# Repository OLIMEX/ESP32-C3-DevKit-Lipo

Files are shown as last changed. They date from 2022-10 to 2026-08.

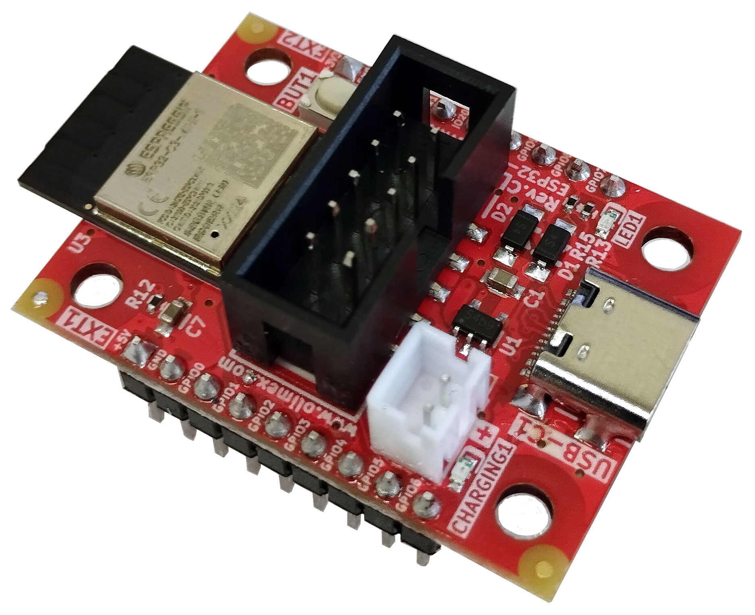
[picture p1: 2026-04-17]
DOCS/Images/ESP32-C3-DevKit-Lipo-1.jpg

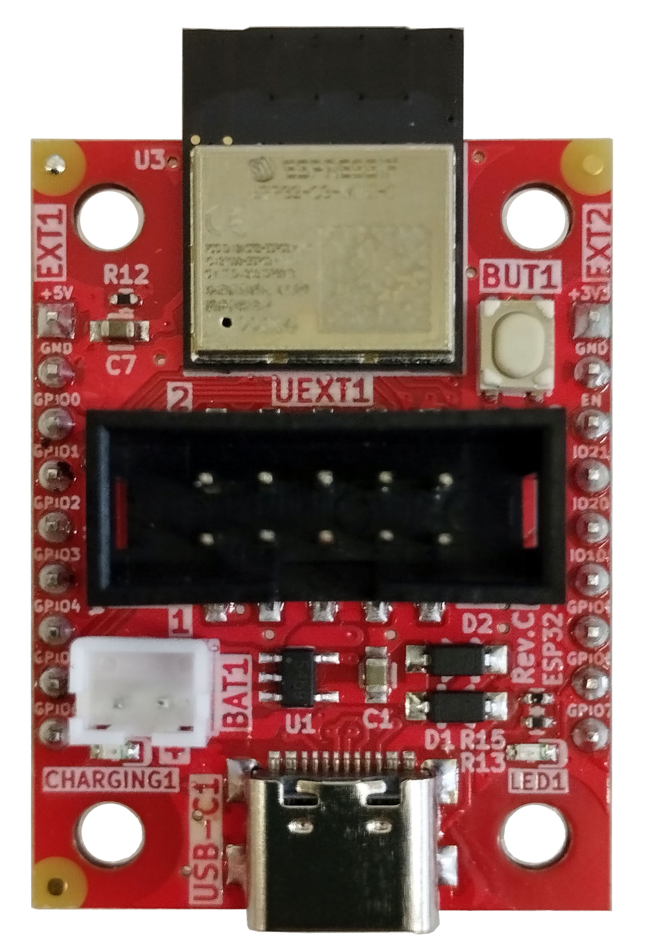
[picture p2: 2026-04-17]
DOCS/Images/ESP32-C3-DevKit-Lipo-2.jpg

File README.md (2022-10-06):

# ESP32-C3-DevKit-Lipo
ESP32-C3-DevKit-Lipo RISC-V development board with USB, JTAG, WIFI, BT5, LiPo battery charger

Product page: https://www.olimex.com/Products/IoT/ESP32-C3/ESP32-C3-DevKit-Lipo/open-source-hardware

## License
* Hardware is released under CERN Open Hardware Licence Version 2 - Strongly Reciprocal https://spdx.org/licenses/CERN-OHL-S-2.0.html
* Software is released under GPL3 License
* Documentation is released under CC BY-SA 3.0 https://creativecommons.org/licenses/by-sa/3.0/

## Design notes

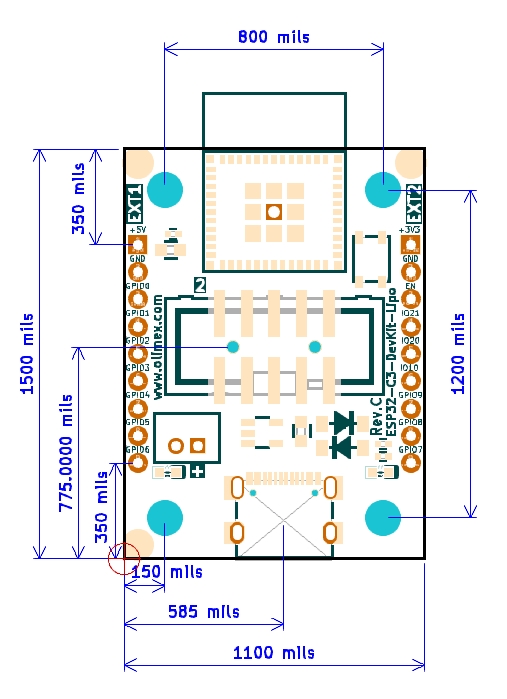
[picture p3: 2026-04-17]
HARDWARE/ESP32-C3-DevKit-Lipo-dimensions.jpg

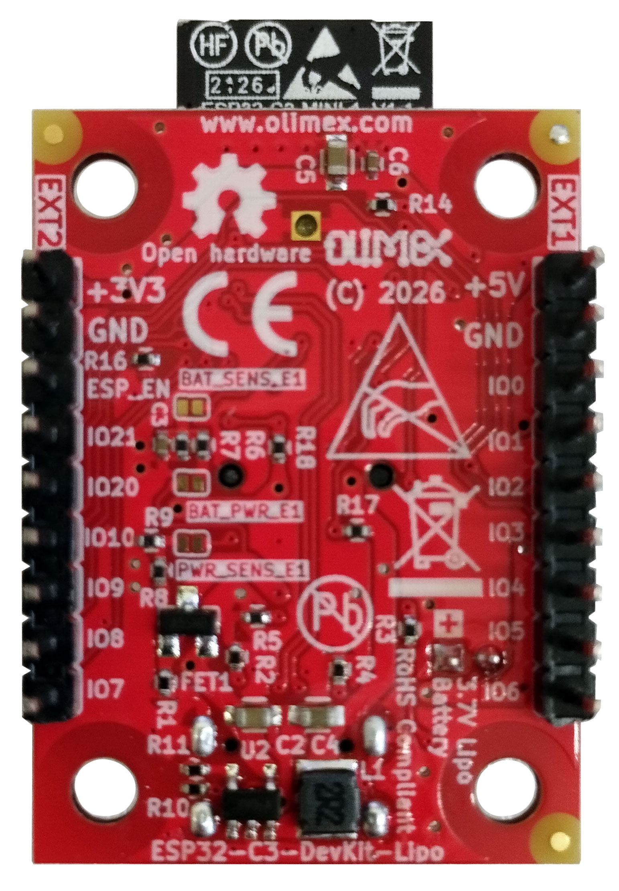
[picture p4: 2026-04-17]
DOCS/Images/ESP32-C3-DevKit-Lipo-3.jpg

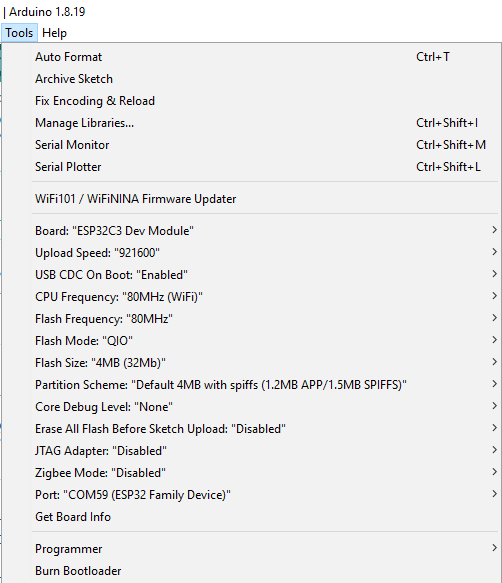
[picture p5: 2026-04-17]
SOFTWARE/Arduino/Arduino-board-settings.jpg

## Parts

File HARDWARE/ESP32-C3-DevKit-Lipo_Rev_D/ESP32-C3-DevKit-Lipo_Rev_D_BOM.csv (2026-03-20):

Id | Designator | Footprint | Quantity | Designation | Supplier and ref
1 | FID1,FID3,FID4,FID6 | Fiducial1x3 | 4 | Fiducial
2 | C1,C2,C5,C4 | C_0603_5MIL_DWS | 4 | 22uF/6.3V/20%/X5R/C0603
3 | R12,R1,R5 | R_0402_5MIL_DWS | 3 | 10k/R0402
4 | R13,R3,R18,R17 | R_0402_5MIL_DWS | 4 | 2.2k/R0402
5 | D2,D1 | SOD-123_1C-2A_KA | 2 | 1N5819S4/SOD123
6 | BAT1 | LIPO_BAT_VERTICAL_DW02S | 1 | DW02S
7 | R15,R14 | R_0402_5MIL_DWS | 2 | 33k/R0402
8 | FID2,FID5 | Fiducial1x3_Paste | 2 | Fiducial
9 | LED1 | LED_0603_KA | 1 | LED/Green/0603
10 | MH1,MH2,MH3,MH4 | Mounting_Hole_Drill-3.3mm_Clerance-7mm | 4 | Mounting_Hole_NPTH
11 | U3 | ESP32--C3--MINI--1 | 1 | ESP32-C3-MINI-1-N4
12 | CHARGING1 | LED_0603_KA | 1 | LED/YELLOW/0603
13 | BUT1 | YTS-A016-X | 1 | YTS-A016-X
14 | U1 | SOT-23-5 | 1 | TP4054-42-SOT25-R
15 | C7 | C_0603_5MIL_DWS | 1 | 1uF/10V/10%/X5R/C0603
16 | USB-C1 | USB2.0_TYPE-C(A40-00119-A52-12) | 1 | USB-C-16P-F(A40-00119-A52-12)
17 | UEXT1 | GBH-254-SMT-10 | 1 | P-B-V-10-LF
18 | BAT_PWR_E1,BAT_SENS_E1,PWR_SENS_E1 | SJ_1_SMALLER | 3 | Opened
19 | R6,R7,R9 | R_0402_5MIL_DWS | 3 | 470k/R0402
20 | R8,R10 | R_0402_5MIL_DWS | 2 | 220k/R0402
21 | L1 | CD32 | 1 | 2.2uH/NRS3015T2R2MNGH/1.5A/3.00x3.00x1.50mm
22 | R11 | R_0402_5MIL_DWS | 1 | 49.9k/1%/R0402
23 | C3,C6 | C_0402_5MIL_DWS | 2 | 100nF/10V/10%/X7R/C0402
24 | FET1 | SOT23 | 1 | IRLML6402TRPbF
25 | EXT1,EXT2 | HN1x9 | 2 | HN1x9
26 | R2,R4 | R_0402_5MIL_DWS | 2 | 5.1k/R0402
27 | U2 | SOT-23-5 | 1 | SY8089AAAC(SOT23-5)
28 | Logo_OLIMEX_2 | Logo_OLIMEX_80 | 1 | Logo_OLIMEX_2
29 | Sign_CE | CE_Sign | 1 | CE_Sign
30 | Sign_Antistatic | Sign_Antistatic | 1 | Sign_Antistatic
31 | Sign_PB-Free | Sign_PB-Free | 1 | Sign_PB-Free
32 | Sign_RecycleBin_1 | Sign_RecycleBin_1 | 1 | Sign_RecycleBin_1
33 | R16 | R_0402_5MIL_DWS | 1 | 100R/R0402

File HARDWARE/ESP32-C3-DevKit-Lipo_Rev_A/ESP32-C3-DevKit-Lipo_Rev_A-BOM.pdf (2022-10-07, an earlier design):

## ESP32-C3-DevKit-Lipo_Rev_A-BOM 09/28/2022

Quantity | Designation | Package | Designator
2 | 2.2k/R0402 | R0402 | R3,R13
2 | 5.1k/R0603 | R0603 | R2,R4
3 | 10k/R0402 | R0402 | R1,R5,R12
2 | 33k/R0402 | R0402 | R14,R15
1 | 49.9k/1%/R0402 | R0402 | R11
2 | 220k/R0402 | R0402 | R8,R10
3 | 470k/R0402 | R0402 | R6,R7,R9
1 | 2.2uH/1.5A/DCR=72mR/ 20%/3.00x3.00x1.50mm/ CD32(NR3015T2R2M) | CD32 | L1
2 | 100nF/10V/10%/X7R/C0402 | C0402 | C3,C6
1 | 1uF/10V/10%/X5R/C0603 | C0603 | C7
4 | 22uF/6.3V/20%/X5R/C0603 | C0603 | C1,C2,C4,C5
2 | 1N5819S4/SOD123 | SOD-123 | D1,D2
1 | LED/YELLOW/0603 | LED_0603 | CHARGING1
1 | LED/Green/0603 | LED_0603 | LED1
1 | WPM2015-3/TR | SOT23 | FET1
1 | BL4054B-42TPRN(SOT23-5) | SOT-23-5 | U1
1 | ESP32-C3-MINI-1-N4 | ESP32- C3- MINI -1 | U3
1 | SY8089AAAC(SOT23-5) | SOT-23-5 | U2
1 | DW02S | DW02S | BAT1
2 | HN1x9 | HN1x9 | EXT1,EXT2
1 | USB-C-16P-F(A40-00119-A52-12) | USB2.0_TYPE-C | USB-C1
1 | WU06S | WU06S | ESP-PROG1
1 | YTS-A016-X | YTS-A016-X | RST1
4 | Opened | SJ_1_SMALLER

BAT_PWR_E1,
BAT_SENS_E1,
PWR_SENS_E1,
3.3V_E1

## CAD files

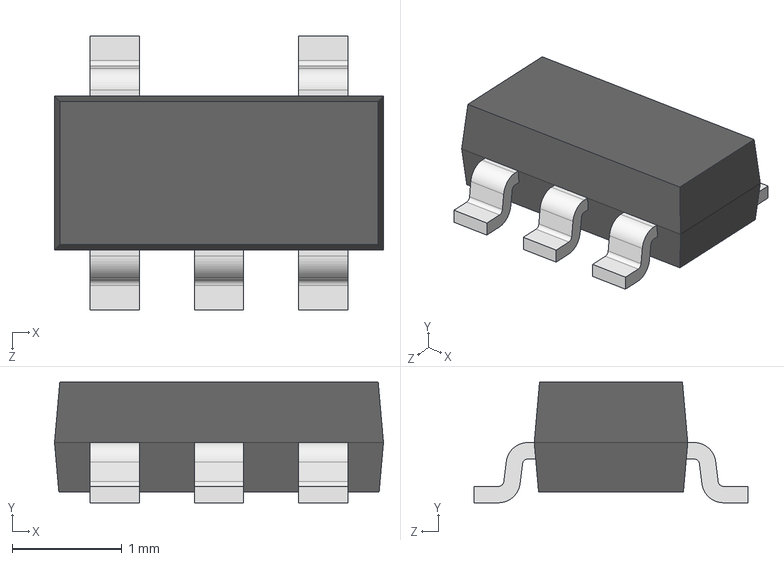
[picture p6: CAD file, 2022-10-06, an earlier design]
HARDWARE/ESP32-C3-DevKit-Lipo_Rev_A/3d/SOT-23-5.step
3.00 x 1.10 x 2.50 mm

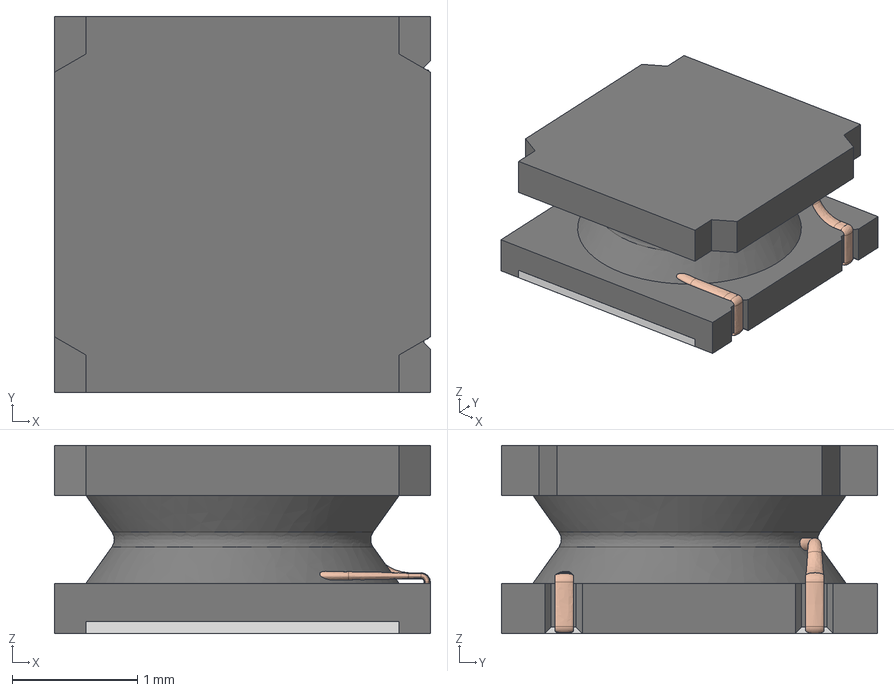
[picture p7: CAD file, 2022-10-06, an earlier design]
HARDWARE/ESP32-C3-DevKit-Lipo_Rev_A/3d/L-CD32_shielded.step
3.00 x 3.00 x 1.50 mm

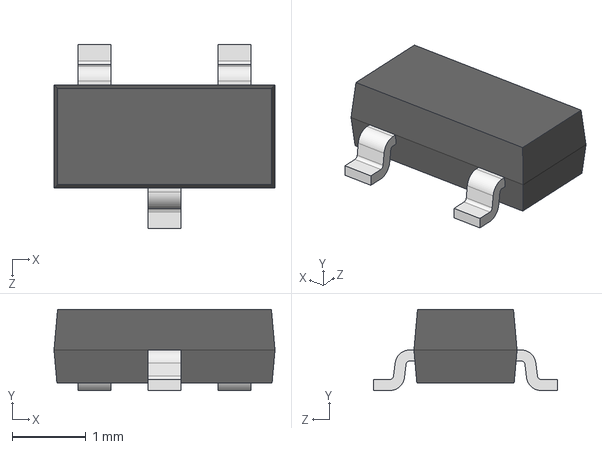
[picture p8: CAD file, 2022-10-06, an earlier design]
HARDWARE/ESP32-C3-DevKit-Lipo_Rev_A/3d/SOT-23.step
3.00 x 1.10 x 2.50 mm

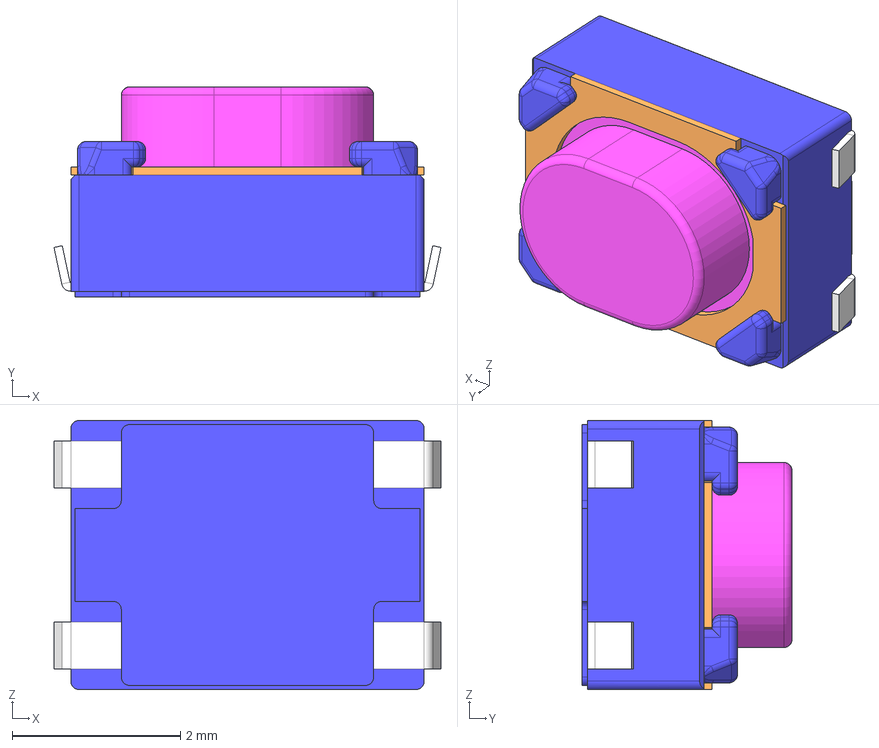
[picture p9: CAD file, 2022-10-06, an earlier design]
HARDWARE/ESP32-C3-DevKit-Lipo_Rev_A/3d/YTS-A016-X(SKRPABE010).stp
4.60 x 2.50 x 3.20 mm

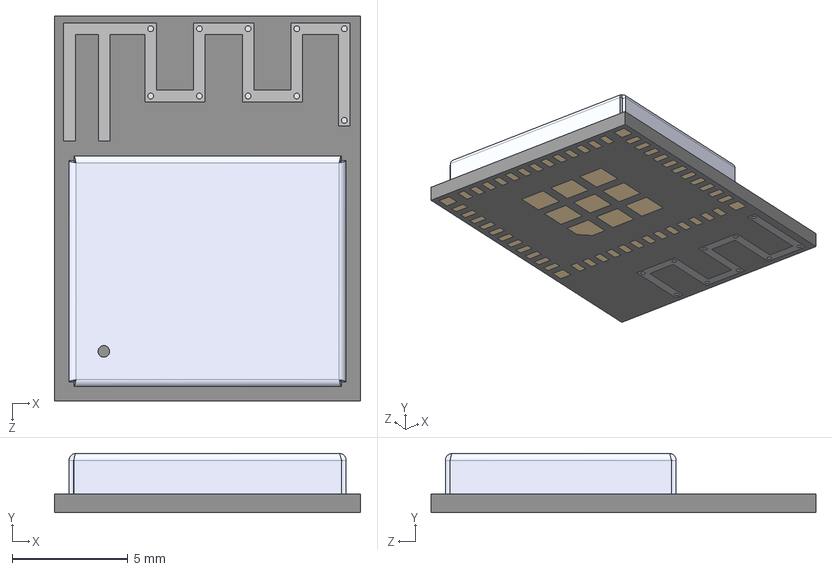
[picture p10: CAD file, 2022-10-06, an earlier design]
HARDWARE/ESP32-C3-DevKit-Lipo_Rev_A/3d/ESP32-C3-MINI-1-N4.STEP
13.2 x 2.55 x 16.6 mm

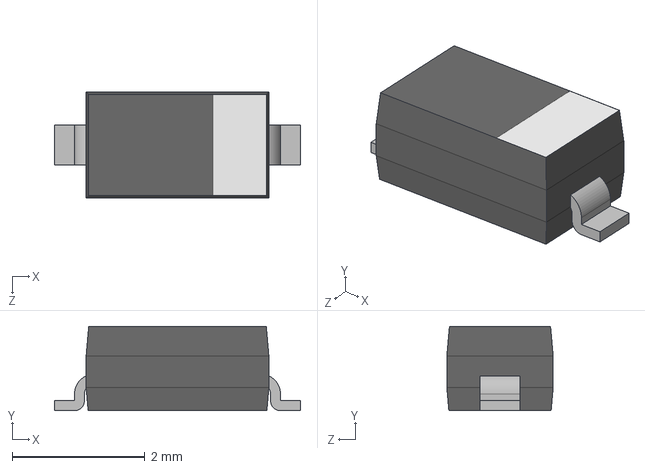
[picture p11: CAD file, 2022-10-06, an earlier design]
HARDWARE/ESP32-C3-DevKit-Lipo_Rev_A/3d/SOD123.step
3.70 x 1.27 x 1.60 mm

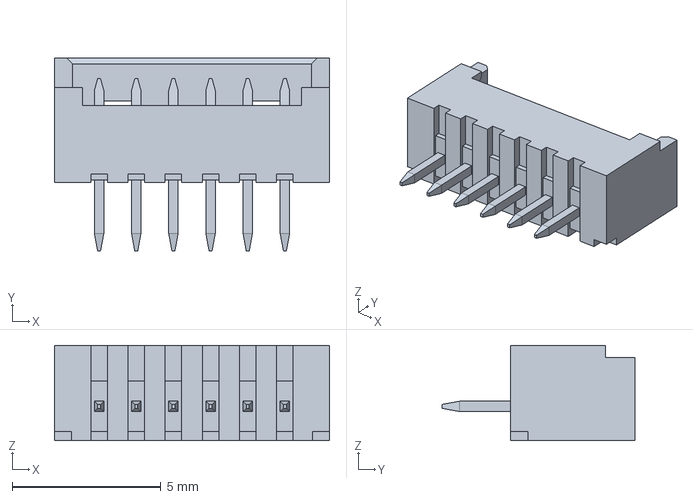
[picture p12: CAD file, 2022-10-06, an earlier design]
HARDWARE/ESP32-C3-DevKit-Lipo_Rev_A/3d/WU06S-Molex_PicoBlade_530470610_1x06_P1.25mm_Vertical.step
9.25 x 6.50 x 3.20 mm

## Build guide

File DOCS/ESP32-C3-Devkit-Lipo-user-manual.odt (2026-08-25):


ESP32-C3-DevKit-Lipo

User Manual

Document version 2.1 August 2026

olimex.com

# What is ESP32-C3-DevKit-Lipo

ESP32-C3-DevKit-Lipo is an Open Source Hardware industrial grade (-25+85ºC) development board with Espressif ESP32-C3-MINI module and WIFI and BLE5 capabilities. It has the following features:

- ESP32-C3-MINI-1N4 module with the following features:
  - RISC-V single core processor running on 160 Mhz
  - 384 KB ROM, 400 KB SRAM (16 KB for cache), 8 KB SRAM in RTC
  - 4 MB embedded flash
  - 2.4 GHz WiFi (802.11 b/g/n) 1T1R mode with data rate up to 150 Mbps
  - Bluetooth® 5 module
- 15 GPIOs
- On-board antenna
- Built-in Li-Po battery charger with STATUS LED, for handheld operations
- Li-Po battery connector for Olimex Li-Po batteries
- User button
- STATUS LED
- UEXT 0.1" step connector
- 4 mount holes
- USB-C connector for powering, debugging, and programming
- EXT1, EXT2 headers with all signals and power supply
- Tiny size: (1.1 x 1.5)" ~ (28 x 38)mm

# Board layout

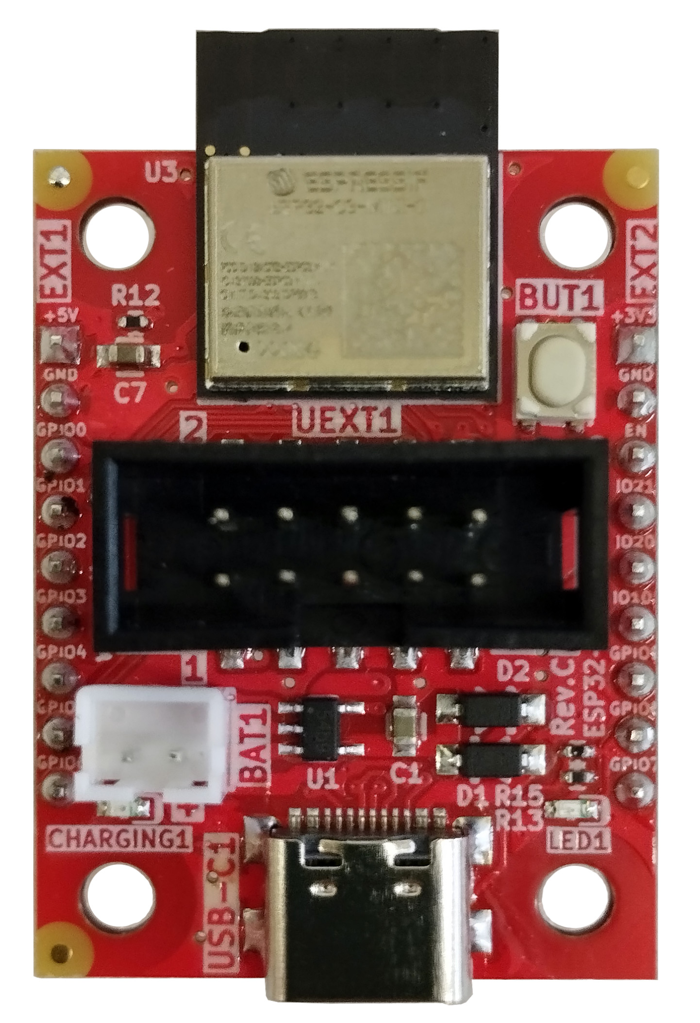
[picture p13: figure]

ESP32-C3-MINI-1

User LED1 - GPIO8

Li-Po battery connector

Battery charger LED indicator

USB C connector

User button BUT1 - GPIO9

UEXT

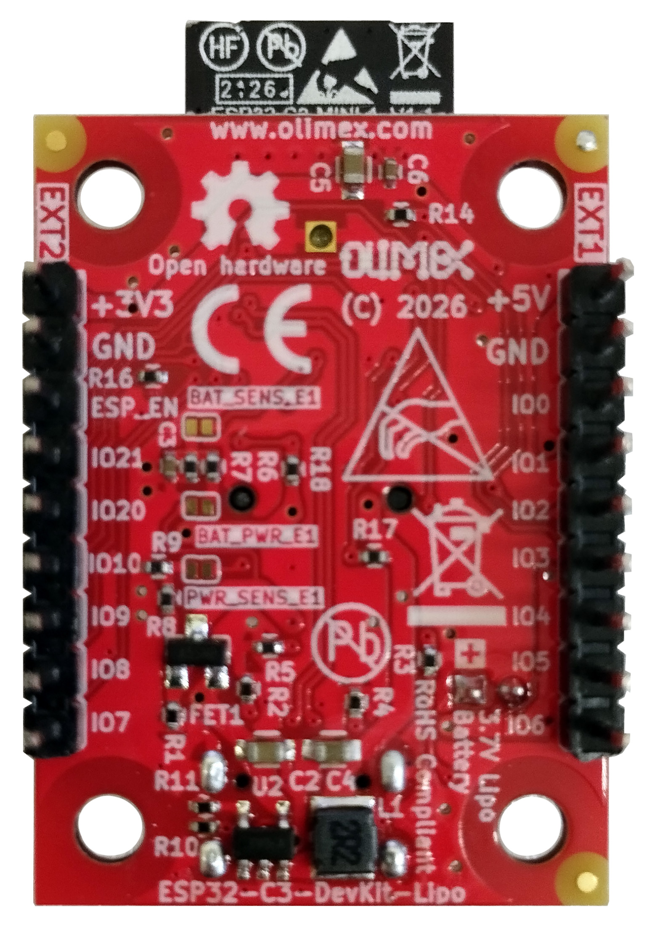
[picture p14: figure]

# ESP32-C3-DevKit-Lipo ordering options

ESP32-C3-DevKit-Lipo can be ordered as:

- ESP32-C3-DevKit-Lipo (https://www.olimex.com/Products/IoT/ESP32-C3/ESP32-C3-DevKit-Lipo/open-source-hardware)

Additional accessories:

- USB-C cable: CABLE-USB-A-C-1M (https://www.olimex.com/Products/Components/Cables/CABLE-USB-A-C-1M/)
- LiPo batteries: Olimex LiPo batteries (https://www.olimex.com/Products/Power/Lipo-battery/)
- Breadboard: BREADBOARD1 (https://www.olimex.com/Products/Breadboarding/BREADBOARD-1/)
- Jumper wires: JW-200x10 (https://www.olimex.com/Products/Breadboarding/JUMPER-WIRES/JW-200x10/), JW-200x10-FM (https://www.olimex.com/Products/Breadboarding/JUMPER-WIRES/JW-200x10-FM/)

# ESP32-C3-DevKit-Lipo Open Source Licensee

ESP32-C3-DevKit-Lipo is Open Source Hardware, ESP32-C3-DevKit-Lipo is certified Open Source Hardware with UID BG000083: https://certification.oshwa.org/bg000083.html

The Hardware files are released under CERN OSHW licensee (https://github.com/OLIMEX/USB-gLINK/blob/master/cern_ohl_s_v2.pdf).

The software is released under GPL 3 licensee (https://github.com/OLIMEX/USB-gLINK/blob/master/LICENSE).

The documentation is released under CC BY-SA 3.0 (https://creativecommons.org/licenses/by-sa/3.0/) licensee.

# ESP32-C3-DevKit-Lipo software installation

How to program the board? Usually you use software that has support for ESP32-C3 chip and then plug the board to the USB. No extra steps with the hardware are needed but if you have trouble you can force the board into bootloader mode – disconnect the USB cable, press and hold button BUT1, connect the USB cable, release button BUT1.

Esspresif guide for Arduino IDE installation (https://docs.espressif.com/projects/arduino-esp32/en/latest/installing.html)

You can find simple Arduino demo here: Button, LED, serial demo (https://github.com/OLIMEX/ESP32-C3-DevKit-Lipo/tree/main/SOFTWARE/Arduino)

Esspressif guide for PlatformIO installation (https://docs.espressif.com/projects/arduino-esp32/en/latest/installing.html)

Espressif ESP-IDF installation (https://github.com/espressif/esp-idf)

JTAG debugging installation (https://docs.espressif.com/projects/esp-idf/en/latest/esp32c3/api-guides/jtag-debugging/index.html)

# ESP32-C3-DevKit-Lipo pinout description

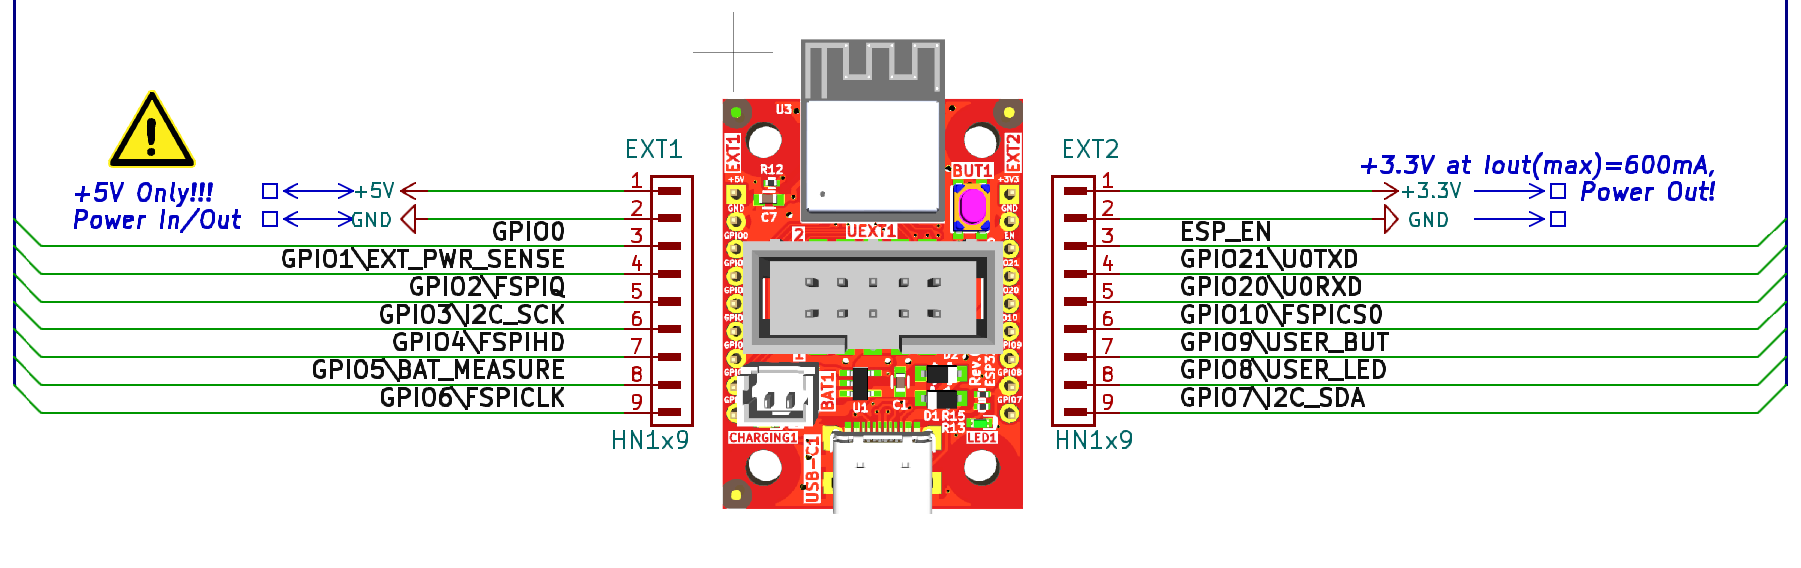
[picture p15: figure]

# UEXT pinout

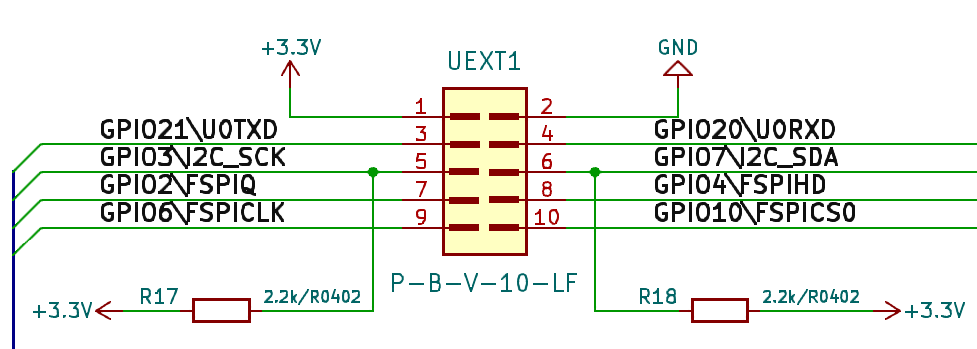
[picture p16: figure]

# External power sense and battery measurement

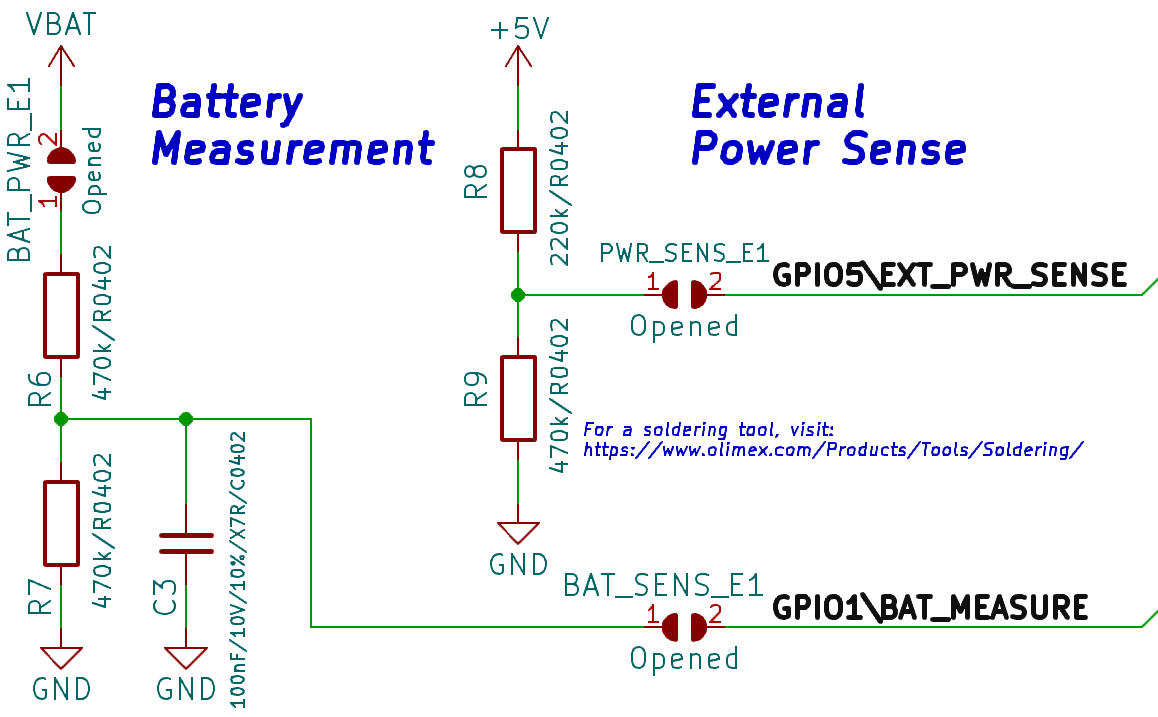
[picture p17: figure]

There are external power sense and battery measurement circuits. By default these are disconnected and can be enabled if you solder together a couple of PTH jumpers.

If you wish to enable the external power sense function, close PWR_SENSE_E1 – this function allows you to detect whether the board is powered from the battery or externally – very helpful if you want to conserve battery when main power supply is missing. Notice the voltage divider R8 and R9 (220K and 470K) and consider the resistor values in your calculations about the threshold. The pin that handles the external power sense function is GPIO5.

If you wish to enable the battery measurement function – you need to close two jumpers (solder pads of each jumper together) – BAT_PWR_E1 and BAT_SENS_E1. This function helps keeping track of the voltage of the battery connected so you can take certain precautions when the voltage of battery goes dangerously low. Notice the voltage divider R6 and R7 (470k and 470k) and consider the resistor values in your calculations. The pin that handles the external power sense function is GPIO1.

Note! The power sense and battery measurement pins were swapped in hardware revision D. Refer to the hardware revision changes document and the schematics for further info.

# ESP32-C3-DevKit-Lipo power supply and consumption

- 0.2A @ Active operation
- 22mA @ Idle
- 3mA @ Sleep
- 20uA @ Power off

# ESP32-C3-DevKit-Lipo dimensions

The dimensions apply to hardware revisions C and newer. Dimensions for revision B boards are available at our GitHub.

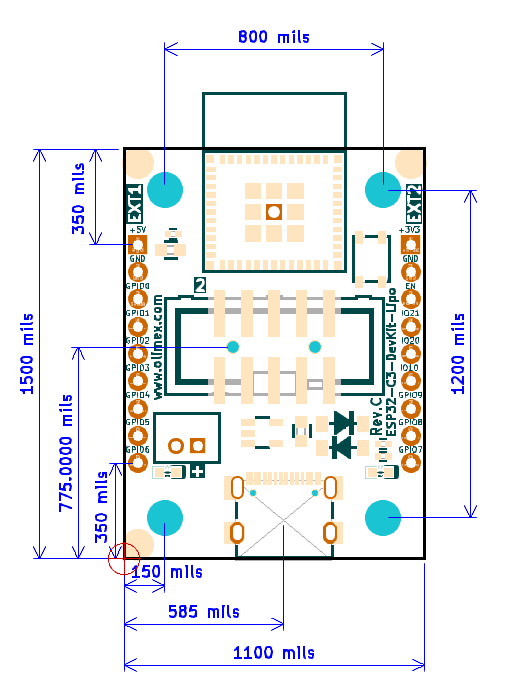
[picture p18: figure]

# ESP32-C3-DevKit-Lipo schematic

ESP32-C3-DevKit-Lipo schematics (including for older revisons) are available at GitHub hardware (https://github.com/OLIMEX/ESP32-C3-DevKit-Lipo/tree/main/HARDWARE)

Hardware revision changes can be found in this text document: Hardware revision changes text at GitHub (https://github.com/OLIMEX/ESP32-C3-DevKit-Lipo/blob/main/HARDWARE/Hardware-revision-changes.txt)

Notice that there were major changes in the hardware design in hardware revision C (added UEXT connector; removed PROG connector; removed reset button but added user button; rotated BAT1 connector; and more).

# Document version history

Revision 1.0 September 2022

- Initial release

Revision 2.0 April 2026

- Edited the document to fit hardware revision C of the board

- Documents for hardware revision B boards available at GitHub for reference

Revision 2.1 August 2026

- Edited the document to fit hardware revision D of the board (the only change is the swap of battery measurement and external power pins)

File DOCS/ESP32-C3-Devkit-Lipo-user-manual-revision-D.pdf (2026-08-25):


# ESP32-C3-DevKit-Lipo User Manual

## Document version 2.1 August 2026

# olimex.com

## Table of Contents

## What is ESP32-C3-DevKit-Lipo

ESP32-C3-DevKit-Lipo is an Open Source Hardware industrial grade (-25+85ºC) development board with Espressif ESP32-C3-MINI module and WIFI and BLE5 capabilities. It has the following features:

- ESP32-C3-MINI-1N4 module with the following features:
- RISC-V single core processor running on 160 Mhz
- 384 KB ROM, 400 KB SRAM (16 KB for cache), 8 KB SRAM in RTC
- 4 MB embedded flash
- 2.4 GHz WiFi (802.11 b/g/n) 1T1R mode with data rate up to 150 Mbps
- Bluetooth® 5 module
- 15 GPIOs
- On-board antenna
- Built-in Li-Po battery charger with STATUS LED, for handheld operations
- Li-Po battery connector for Olimex Li-Po batteries
- User button
- STATUS LED
- UEXT 0.1" step connector
- 4 mount holes
- USB-C connector for powering, debugging, and programming
- EXT1, EXT2 headers with all signals and power supply
- Tiny size: (1.1 x 1.5)" ~ (28 x 38)mm

## Board layout

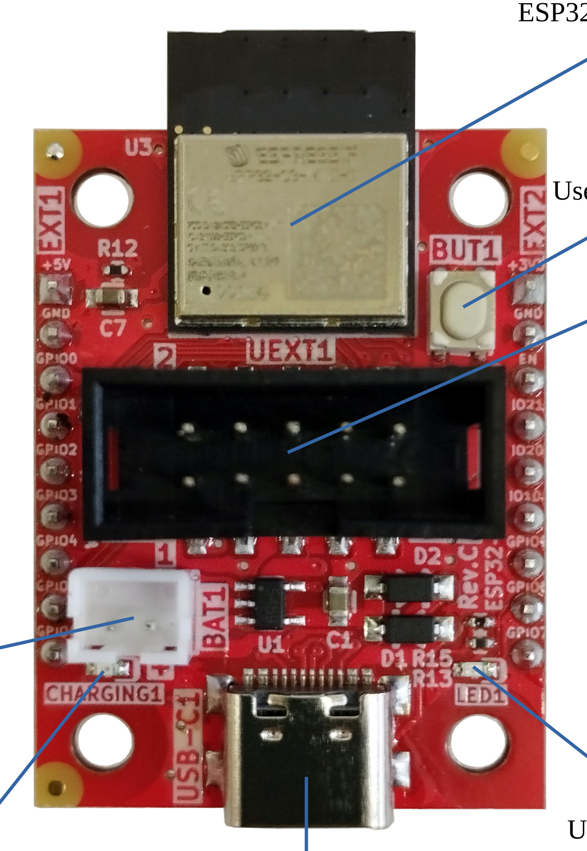
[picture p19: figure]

User LED1 - GPIO8

Li-Po battery
connector

Battery charger LED
indicator
USB C
connector

User button BUT1 - GPIO9

ESP32-C3-MINI-1

UEXT


## ESP32-C3-DevKit-Lipo ordering options

ESP32-C3-DevKit-Lipo can be ordered as:
- ESP32-C3-DevKit-Lipo (https://www.olimex.com/Products/IoT/ESP32-C3/ESP32-C3-DevKit-Lipo/open-source-hardware)
Additional accessories:
- USB-C cable: CABLE-USB-A-C-1M (https://www.olimex.com/Products/Components/Cables/CABLE-USB-A-C-1M/)
- LiPo batteries: Olimex LiPo batteries (https://www.olimex.com/Products/Power/Lipo-battery/)
- Breadboard: BREADBOARD1 (https://www.olimex.com/Products/Breadboarding/BREADBOARD-1/)
- Jumper wires: JW-200x10, (https://www.olimex.com/Products/Breadboarding/JUMPER-WIRES/JW-200x10/) JW-200x10-FM (https://www.olimex.com/Products/Breadboarding/JUMPER-WIRES/JW-200x10-FM/)

## ESP32-C3-DevKit-Lipo Open Source Licensee

ESP32-C3-DevKit-Lipo is Open Source Hardware, ESP32-C3-DevKit-Lipo is certified Open Source Hardware with UID BG000083: https://certification.oshwa.org/bg000083.html

The Hardware files are released under CERN OSHW licensee. (https://github.com/OLIMEX/USB-gLINK/blob/master/cern_ohl_s_v2.pdf)
The software is released under GPL 3 licensee. (https://github.com/OLIMEX/USB-gLINK/blob/master/LICENSE)
The documentation is released under CC BY-SA 3.0 (https://creativecommons.org/licenses/by-sa/3.0/) licensee.

## ESP32-C3-DevKit-Lipo software installation

How to program the board? Usually you use software that has support for ESP32-C3 chip and then plug the board to the USB. No extra steps with the hardware are needed but if you have trouble you can force the board into bootloader mode – disconnect the USB cable, press and hold button BUT1, connect the USB cable, release button BUT1.

Esspresif guide for Arduino IDE installation (https://docs.espressif.com/projects/arduino-esp32/en/latest/installing.html)
You can find simple Arduino demo here: Button, LED, serial demo (https://github.com/OLIMEX/ESP32-C3-DevKit-Lipo/tree/main/SOFTWARE/Arduino)

Esspressif guide for PlatformIO installation (https://docs.espressif.com/projects/arduino-esp32/en/latest/installing.html)
Espressif ESP-IDF installation (https://github.com/espressif/esp-idf)
JTAG debugging installation (https://docs.espressif.com/projects/esp-idf/en/latest/esp32c3/api-guides/jtag-debugging/index.html)

## ESP32-C3-DevKit-Lipo pinout description

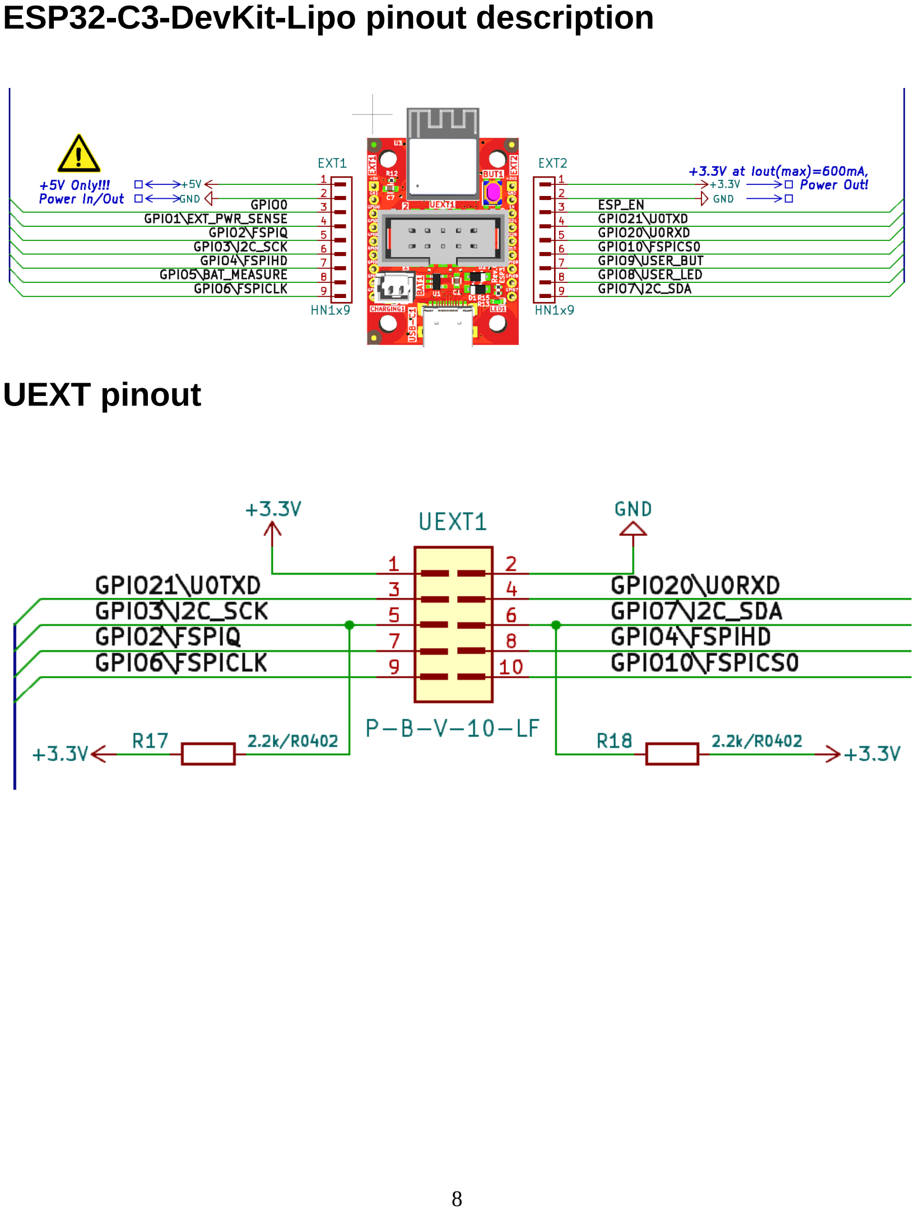
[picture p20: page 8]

## UEXT pinout

## External power sense and battery measurement


There are external power sense and battery measurement circuits. By default these are disconnected and can be enabled if you solder together a couple of PTH jumpers.
If you wish to enable the external power sense function, close PWR_SENSE_E1 – this function allows you to detect whether the board is powered from the battery or externally – very helpful if you want to conserve battery when main power supply is missing. Notice the voltage divider R8 and R9 (220K and 470K) and consider the resistor values in your calculations about the threshold. The pin that handles the external power sense function is GPIO5.
If you wish to enable the battery measurement function – you need to close two jumpers (solder pads of each jumper together) – BAT_PWR_E1 and BAT_SENS_E1. This function helps keeping track of the voltage of the battery connected so you can take certain precautions when the voltage of battery goes dangerously low. Notice the voltage divider R6 and R7 (470k and 470k) and consider the resistor values in your calculations. The pin that handles the external power sense function is GPIO1.
Note! The power sense and battery measurement pins were swapped in hardware revision D. Refer to the hardware revision changes document and the schematics for further info.

## ESP32-C3-DevKit-Lipo power supply and consumption

- 0.2A @ Active operation
- 22mA @ Idle
- 3mA @ Sleep
- 20uA @ Power off

## ESP32-C3-DevKit-Lipo dimensions

The dimensions apply to hardware revisions C and newer. Dimensions for revision B boards are available at our GitHub.

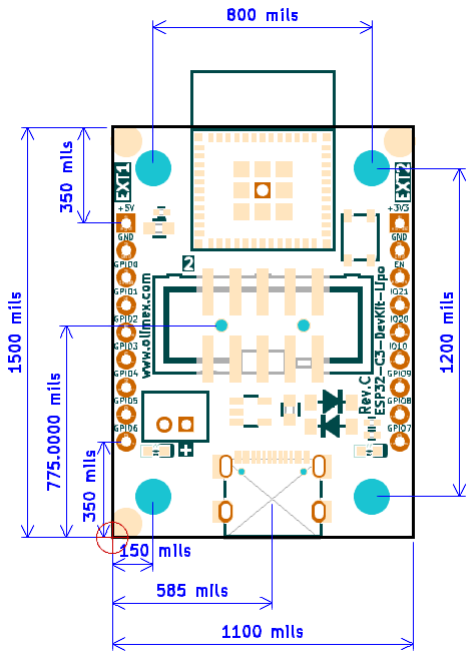
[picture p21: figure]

## ESP32-C3-DevKit-Lipo schematic

ESP32-C3-DevKit-Lipo schematics (including for older revisons) are available at GitHub hardware (https://github.com/OLIMEX/ESP32-C3-DevKit-Lipo/tree/main/HARDWARE) Hardware revision changes can be found in this text document: Hardware revision changes text at GitHub (https://github.com/OLIMEX/ESP32-C3-DevKit-Lipo/blob/main/HARDWARE/Hardware-revision-changes.txt)
Notice that there were major changes in the hardware design in hardware revision C (added UEXT connector; removed PROG connector; removed reset button but added user button; rotated BAT1 connector; and more).

## Document version history

Revision 1.0 September 2022
- Initial release
Revision 2.0 April 2026
- Edited the document to fit hardware revision C of the board
- Documents for hardware revision B boards available at GitHub for reference
Revision 2.1 August 2026
- Edited the document to fit hardware revision D of the board (the only change is the swap of battery measurement and external power pins)

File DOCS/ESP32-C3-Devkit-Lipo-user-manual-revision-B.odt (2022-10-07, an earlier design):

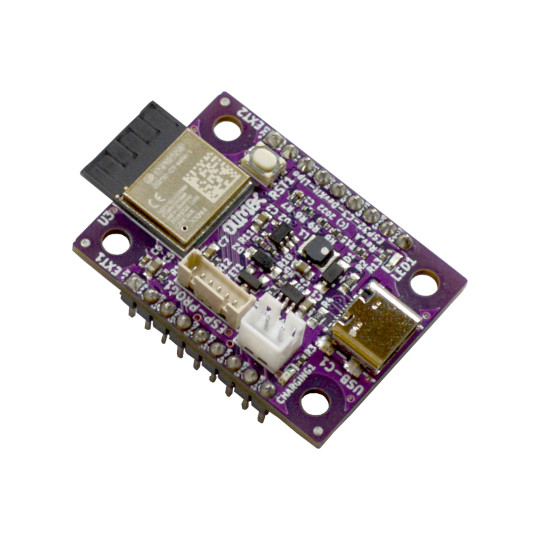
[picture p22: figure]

ESP32-C3-DevKit-Lipo

User Manual

Rev.1.0 September 2022

olimex.com

# What is ESP32-C3-DevKit-Lipo

ESP32-C3-DevKit-Lipo is Open Source Hardware Industrial grade -25+85ºC development board with:

- ESP32-C3 RISC-V single core processor runninig on 160 Mhz
- 384 KB ROM, 400 KB SRAM (16 KB for cache), 8 KB SRAM in RTC
- 4 MB embedded flash
- 2.4 GHz WiFi (802.11 b/g/n) 1T1R mode with data rate up to 150 Mbps
- Bluetooth® 5 module
- 15 GPIOs
- Onboard antenna
- Build in LiPo battery charger with STATUS LED, for handheld operations
- Lipo battery connector for Olimex LiPo batteries
- RESET button
- STATUS LED
- ICSP programming connector for rescue with ESP-PROG-C
- 4 mount holes
- USB-C connector for Debugging and Programming
- two soldered EXT headers with all signals and power supply

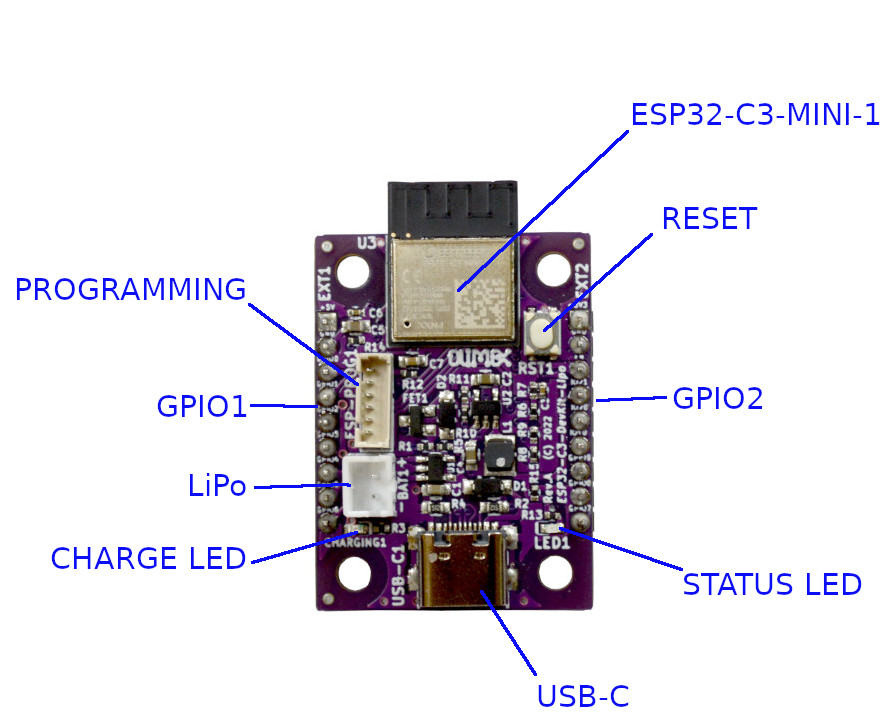
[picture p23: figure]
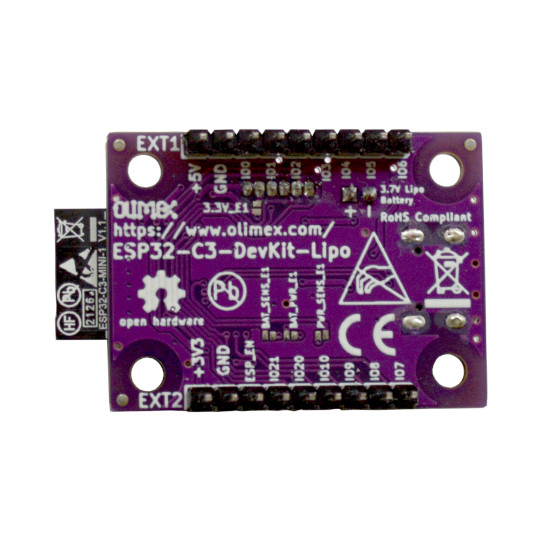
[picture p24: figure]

# ESP32-C3-DevKit-Lipo ordering options

ESP32-C3-DevKit-Lipo can be ordered as:

- ESP32-C3-DevKit-Lipo (https://www.olimex.com/Products/IoT/ESP32-C3/ESP32-C3-DevKit-Lipo/open-source-hardware)

Additional accessories:

USB-C cable: CABLE-USB-A-C-1M (https://www.olimex.com/Products/Components/Cables/CABLE-USB-A-C-1M/)

LiPo batteries: Olimex LiPo batteries (https://www.olimex.com/Products/Power/Lipo-battery/)

Breadboard: BREADBOARD1 (https://www.olimex.com/Products/Breadboarding/BREADBOARD-1/)

Jumper wires: JW-200x10 (https://www.olimex.com/Products/Breadboarding/JUMPER-WIRES/JW-200x10/), JW-200x10-FM (https://www.olimex.com/Products/Breadboarding/JUMPER-WIRES/JW-200x10-FM/)

# ESP32-C3-DevKit-Lipo Open Source Licensee

ESP32-C3-DevKit-Lipo is Open Source Hardware.

The Hardware files are released under CERN OSHW licensee (https://github.com/OLIMEX/USB-gLINK/blob/master/cern_ohl_s_v2.pdf).

The software is released under GPL 3 licensee (https://github.com/OLIMEX/USB-gLINK/blob/master/LICENSE).

The documentation is released under CC BY-SA 3.0 (https://creativecommons.org/licenses/by-sa/3.0/) licensee.

# ESP32-C3-DevKit-Lipo software installation

Esspresif guide for Arduino IDE installation (https://docs.espressif.com/projects/arduino-esp32/en/latest/installing.html).

Esspressif guide for PlatformIO installation (https://docs.espressif.com/projects/arduino-esp32/en/latest/installing.html).

Espressif ESP-IDF installation (https://github.com/espressif/esp-idf).

JTAG debugging installation (https://docs.espressif.com/projects/esp-idf/en/latest/esp32c3/api-guides/jtag-debugging/index.html).

# ESP32-C3-DevKit-Lipo pinout description:

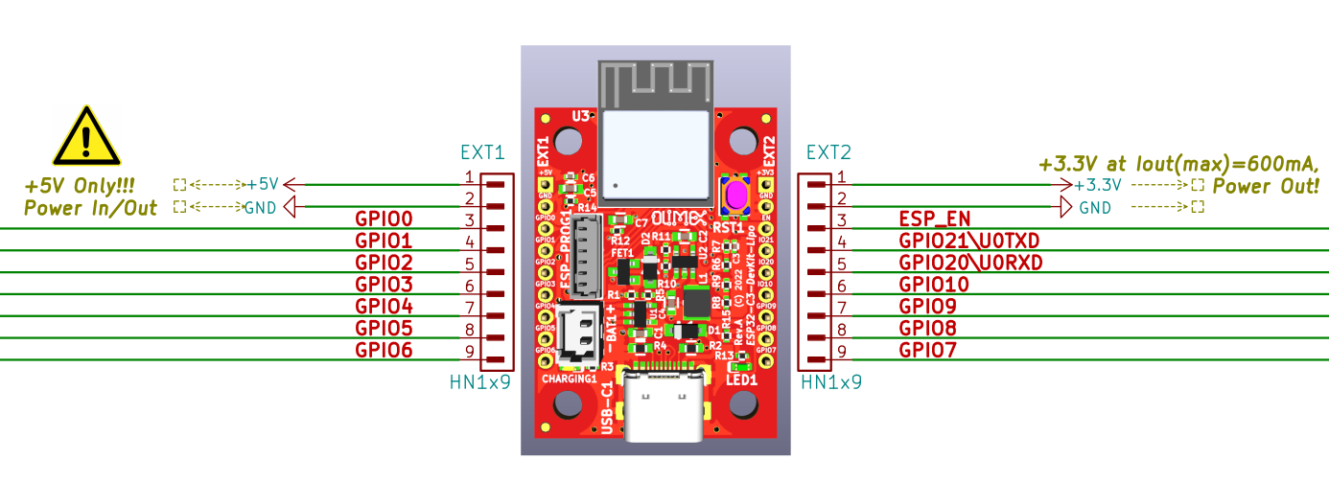
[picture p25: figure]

# ESP32-C3-DevKit-Lipo power supply and consumption

- 0.2A @ Active operation
- 22mA @ Idle
- 3mA @ Sleep
- 20 uA @ Power off

# ESP32-C3-DevKit-Lipo dimensions

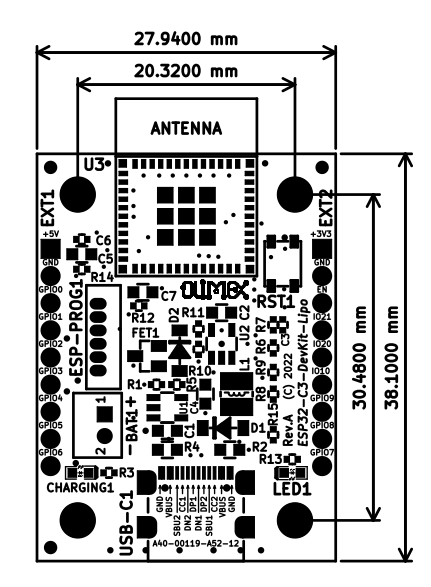
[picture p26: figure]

# ESP32-C3-DevKit-Lipo schematic

# ESP32-C3-DevKit-Lipo schematic on GitHub (https://github.com/OLIMEX/ESP32-C3-DevKit-Lipo/HARDWARE/ESP32-C3-DevKit-Lipo_Rev_A/ESP32-C3-DevKit-Lipo_Rev_A.pdf)

# Revision History

Revision 1.0 September 2022

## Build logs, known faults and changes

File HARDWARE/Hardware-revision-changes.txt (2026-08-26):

========
Hardware revision B
========

Initial release

========
Hardware revision C
========

Major changes compared to revision B:

1. Moved the project to KiCAD 7.
2. Added UEXT connector.
3. Removed ESP-PROG connector.
4. Rotated BAT1 connector.
5. Changed some GPIOs - battery measruement pin is now GPIO5 and external power sense is GPIO1.

========
Hardware revision D
========

Preliminary, unreleased.

1. Reverted the change to the GPIOs responsible for battery sense and battery measurement. This is because ADC2 is used by the WIFI module and there might be confilct.
GPIO5 now used for external power sense and GPIO1 now used for battery measurement.

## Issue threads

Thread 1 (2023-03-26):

GPIO 20 and GPIO 21

elpiel, 2023-03-26:
I see that GPIO 20 has a voltage divider as well as GPIO 21 for power sensing of the 5v.

Could you explain how these pins can be used for reading out the battery measurement and the external power?

Especially what are BAT_PWR_E1, BAT_SENS_E1 and PWR_SENS_E1? And how they can be used.
I tried reading them with ADC but I believe that I'm missing out something because I always get 2000 (with 11db atten. set up).

DanKoloff, 2023-03-28:
By default both external power sense and battery measurement functions are not enabled. To enable external power sense you need to close jumper PWR-SENS_E1 (solder its pads together), then use GPIO4 for monitoring.

Same for battery measurement but you need to close two other SMT jumpers, BAT_PWR_E1 and BAT_SENS_E1. After closing the jumpers use GPIO3 for measurement.

We have code for another board, just put the proper GPIOs:

https://github.com/OLIMEX/ESP32-POE/blob/master/SOFTWARE/ARDUINO/ESP32_PoE_PowerReading/ESP32_PoE_PowerReading.ino

elpiel, 2023-03-28:
#### ADC power sense & battery measurement
Great! I did solder them but now I always get a value of 4095 on the ADC reading with 11db attenuation.

#### 3.3V_E1
There's another enable jumper, would you mind telling me when should I use it? It's connected to the debug

PS: It's good to mention that I have the Rev A.

DanKoloff, 2023-03-28:
Did you try the code I linked with:

#define POWER_SENSE 4
#define BATTERY 3

Usually you would never need to close 3.3V_E1. It is used when you want to power your ESP32-C3-DevKit-Lipo board from the ESP-PROG1 connector, but you usually power the board from the USB. ESP-PROG1 connector fits ESP-PROG tool:

https://www.olimex.com/Products/IoT/Programmer/ESP-PROG/open-source-hardware

elpiel, 2023-03-28:
Yes, I did check it, however, I'm using Rust and I also asked in the esp-rs matrix, it appears that they currently don't do calibration in the HAL (hardware abstraction layer) crate and documentation on this is very scares to implement it.
This is the cause of the issue.

elpiel, 2023-03-28:
Would be nice to mention GPIO3 & GPIO4 in the docs.
It's a very useful feature to have battery measurement and power sense the way you've added it to board.

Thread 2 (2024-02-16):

Serial Monitor not working

dreaquil, 2024-02-16:
I am trying to get a simple sketch running on the ESP32 C3. I am able to upload the sketch successfully but the serial monitor is blank. Any thoughts as to why this might be?

This is the sketch:

```
void setup(){
  Serial.begin(115200);
}

void loop(){
  Serial.println("Hello from ESP32-C3!");
  delay(1000);
}
```

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

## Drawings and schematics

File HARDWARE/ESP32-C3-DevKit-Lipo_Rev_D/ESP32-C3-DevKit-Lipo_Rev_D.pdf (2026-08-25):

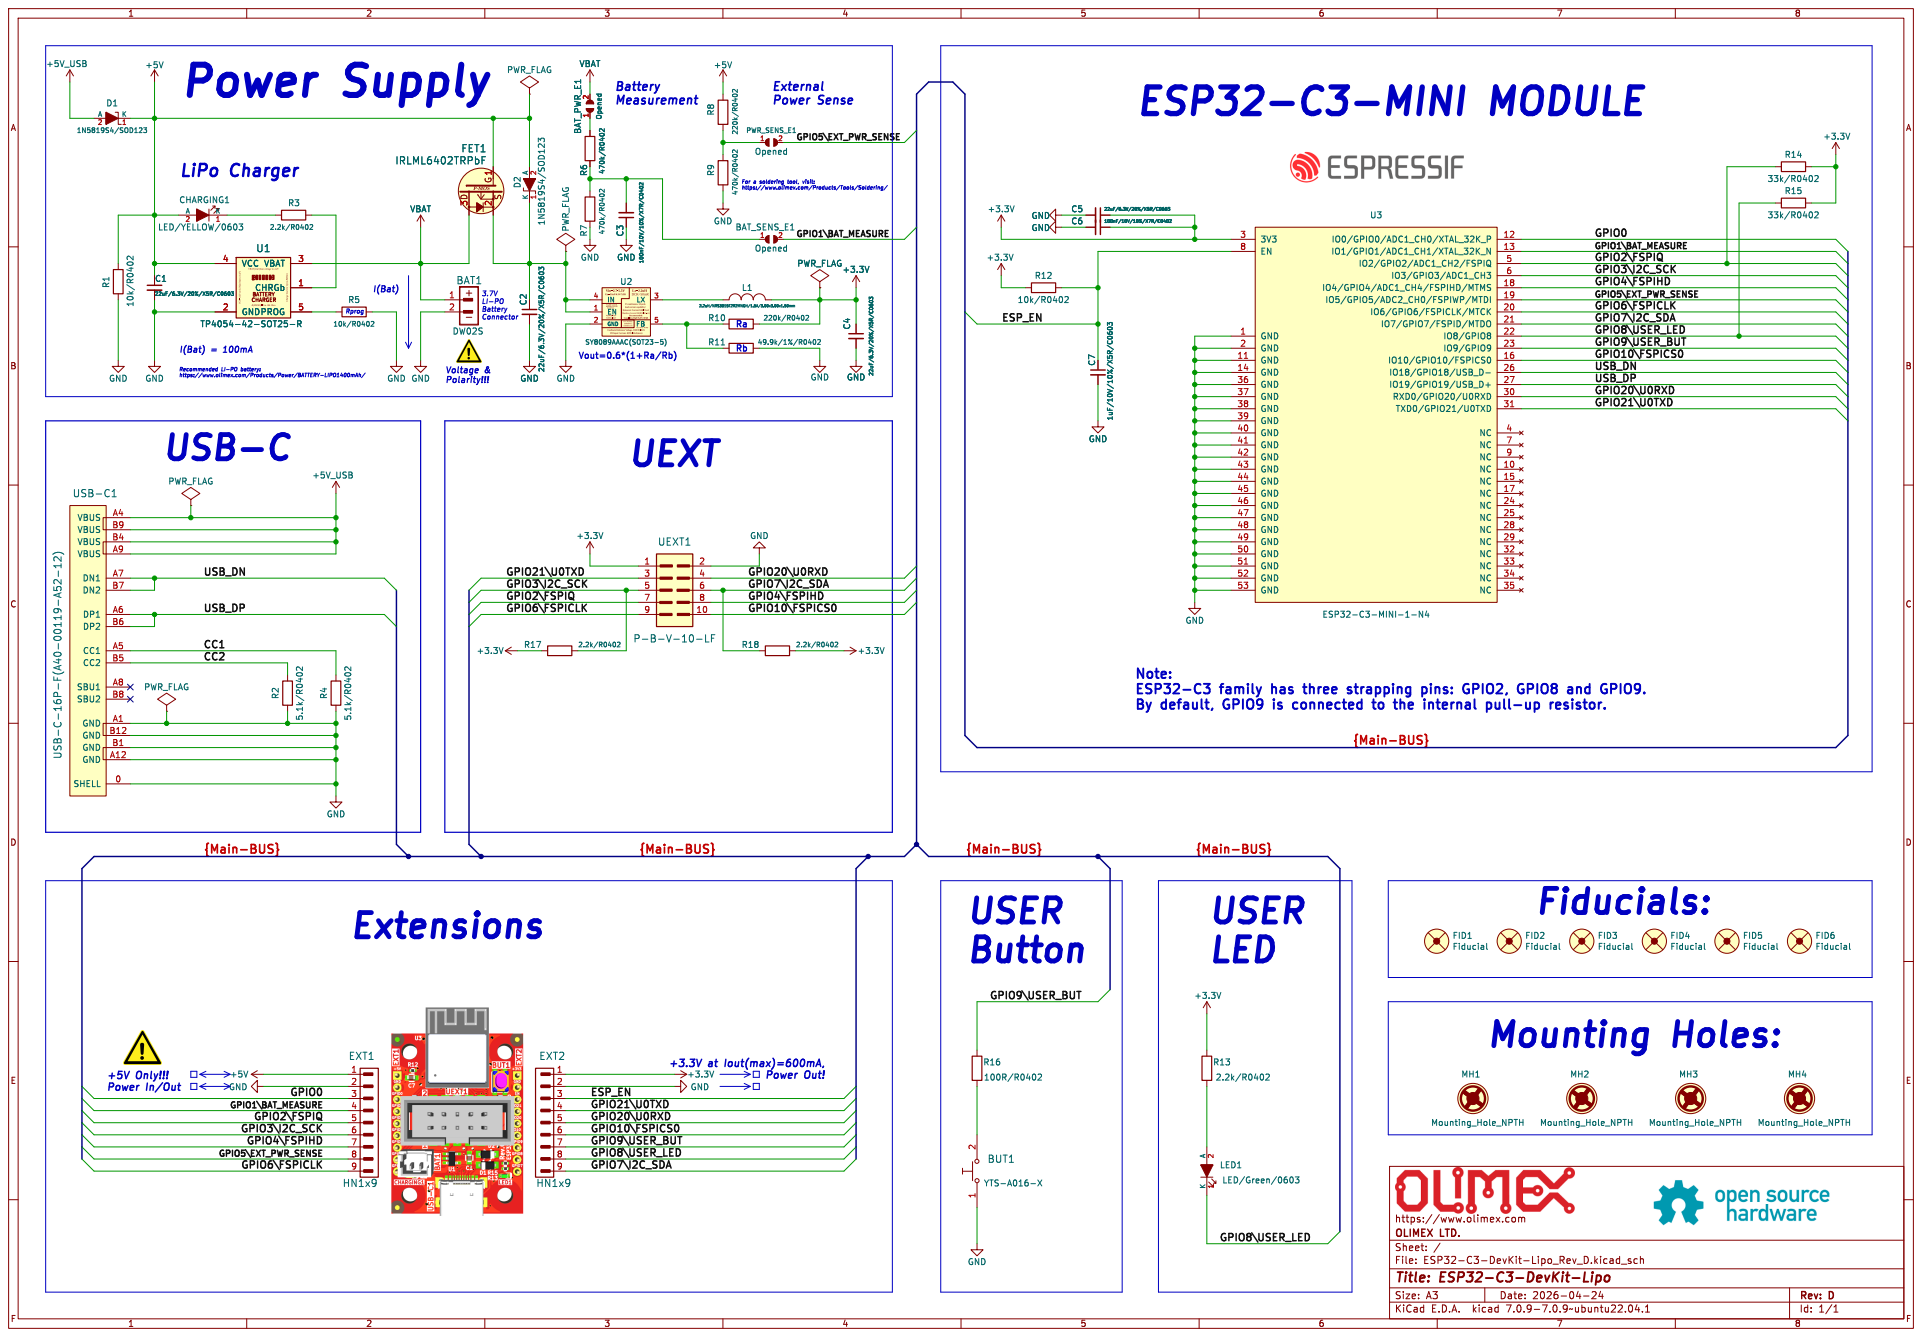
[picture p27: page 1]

Rprog Recommended LI-PO battery: https://www.olimex.com/Products/Power/BATTERY-LIPO1400mAh/ I(Bat) = 100mA
TP4054-42-SOT25-R

Donotfloat. Enablecontrol. FB Input Current,I(FB)=50nA(max) FeedbackReferenceVoltage,V(REF)=0.6V

+5V Only!!! Power In/Out

+3.3V at Iout(max)=600mA, Power Out!

Id: 1/1 Title: ESP32-C3-DevKit-Lipo

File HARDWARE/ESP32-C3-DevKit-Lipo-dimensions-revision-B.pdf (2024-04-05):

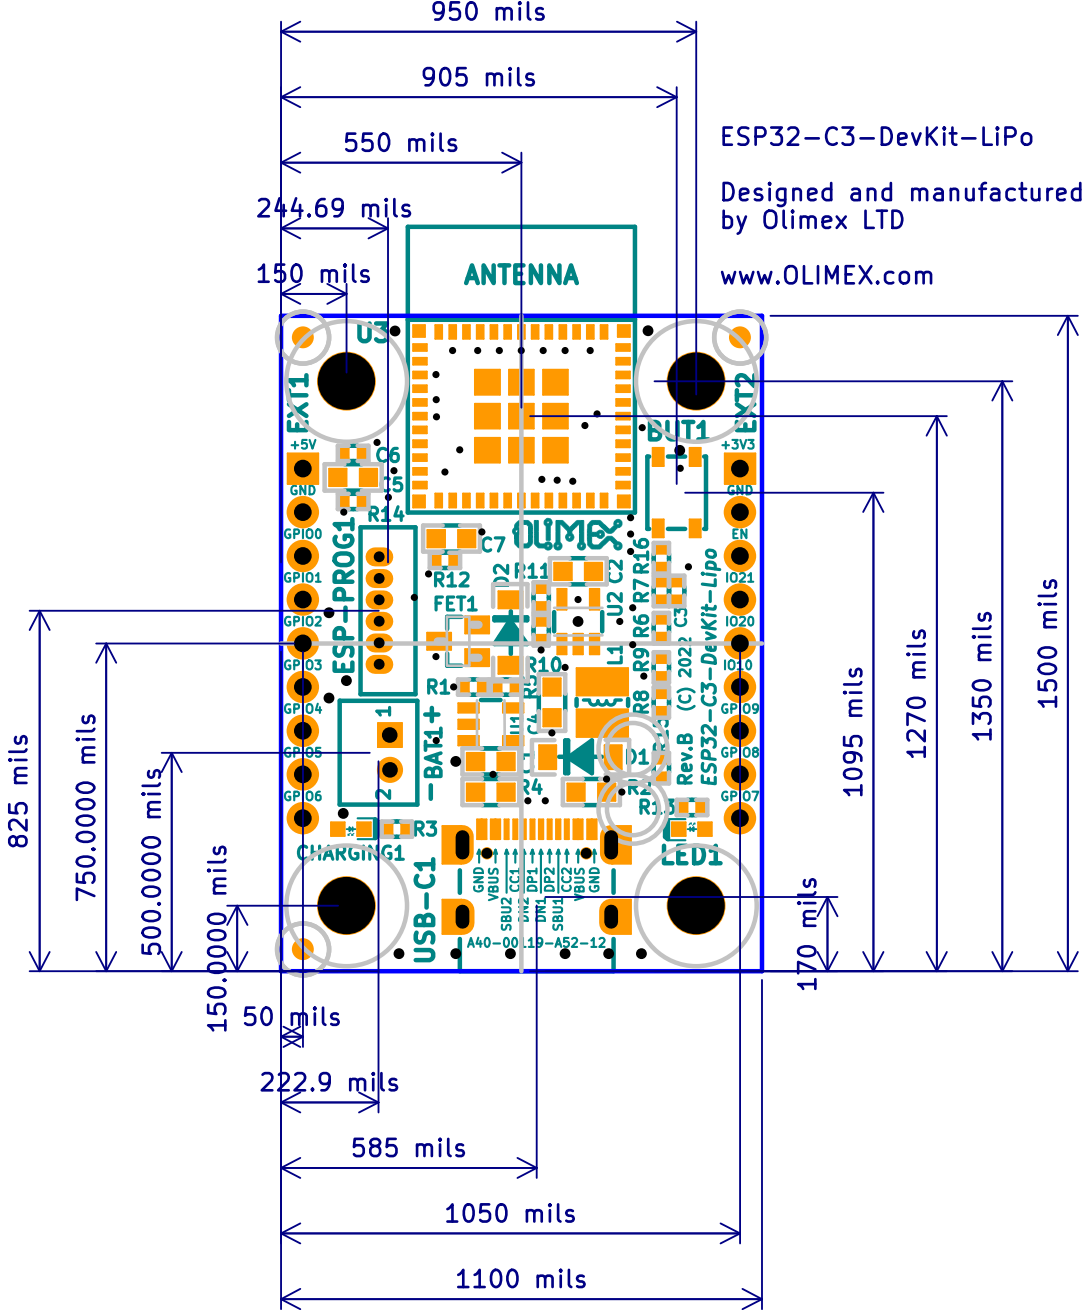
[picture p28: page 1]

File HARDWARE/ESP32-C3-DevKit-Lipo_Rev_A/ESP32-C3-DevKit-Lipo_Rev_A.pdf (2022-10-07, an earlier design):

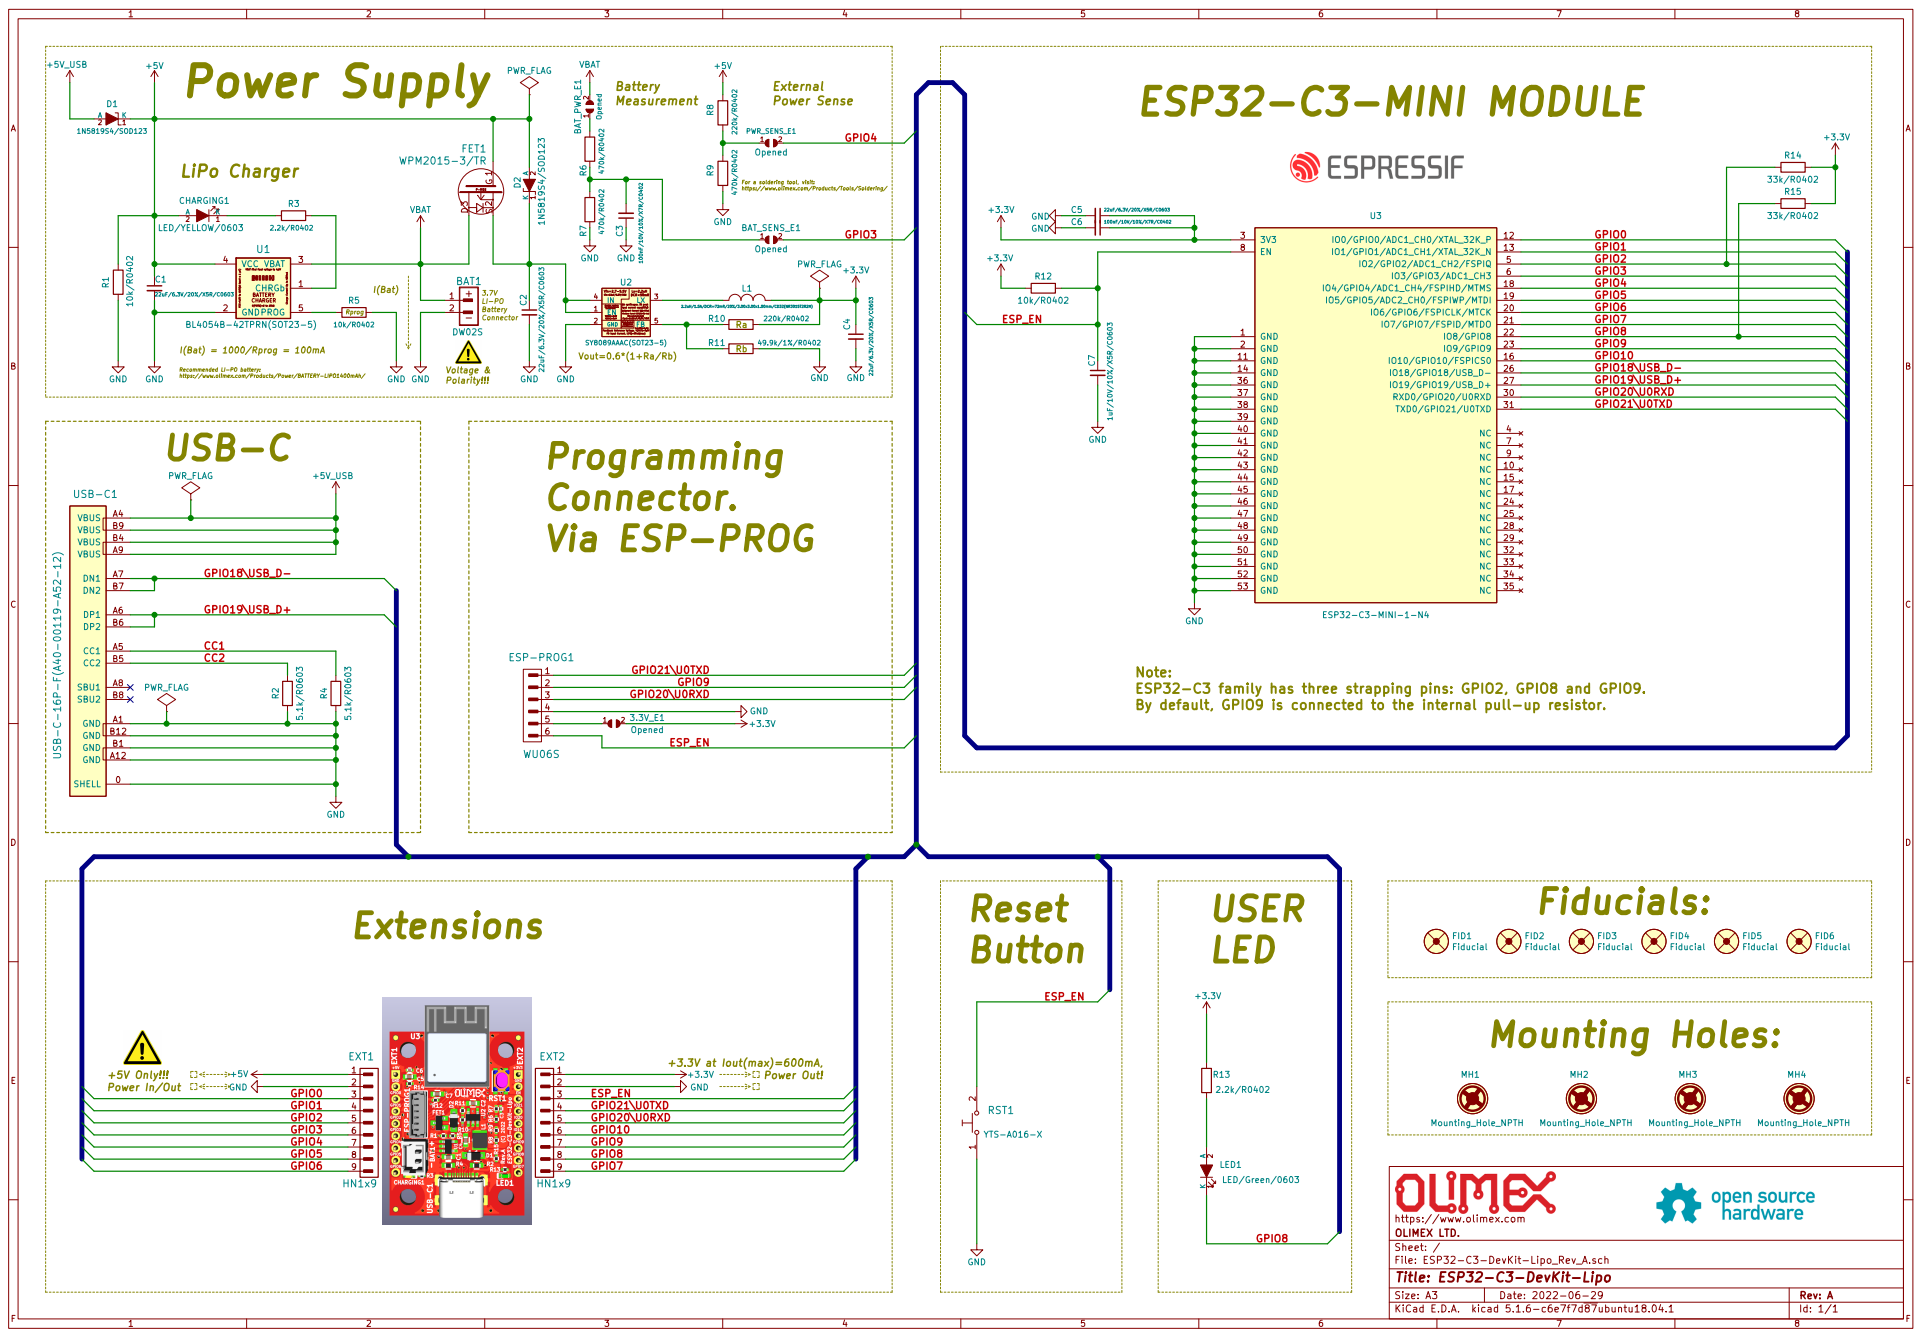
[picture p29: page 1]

load current capability! Lx=2.2uH

Do not float. Enable control. FB Input Current, I(FB)=50nA(max) Feedback Reference Voltage, V(REF)=0.6V

Note: ESP32-C3 family has three strapping pins: GPIO2, GPIO8 and GPIO9.

By default, GPIO9 is connected to the internal pull-up resistor.

+5V Only!!! Power In/Out

+3.3V at Iout(max)=600mA, Power Out!

Id: 1/1 Title: ESP32-C3-DevKit-Lipo

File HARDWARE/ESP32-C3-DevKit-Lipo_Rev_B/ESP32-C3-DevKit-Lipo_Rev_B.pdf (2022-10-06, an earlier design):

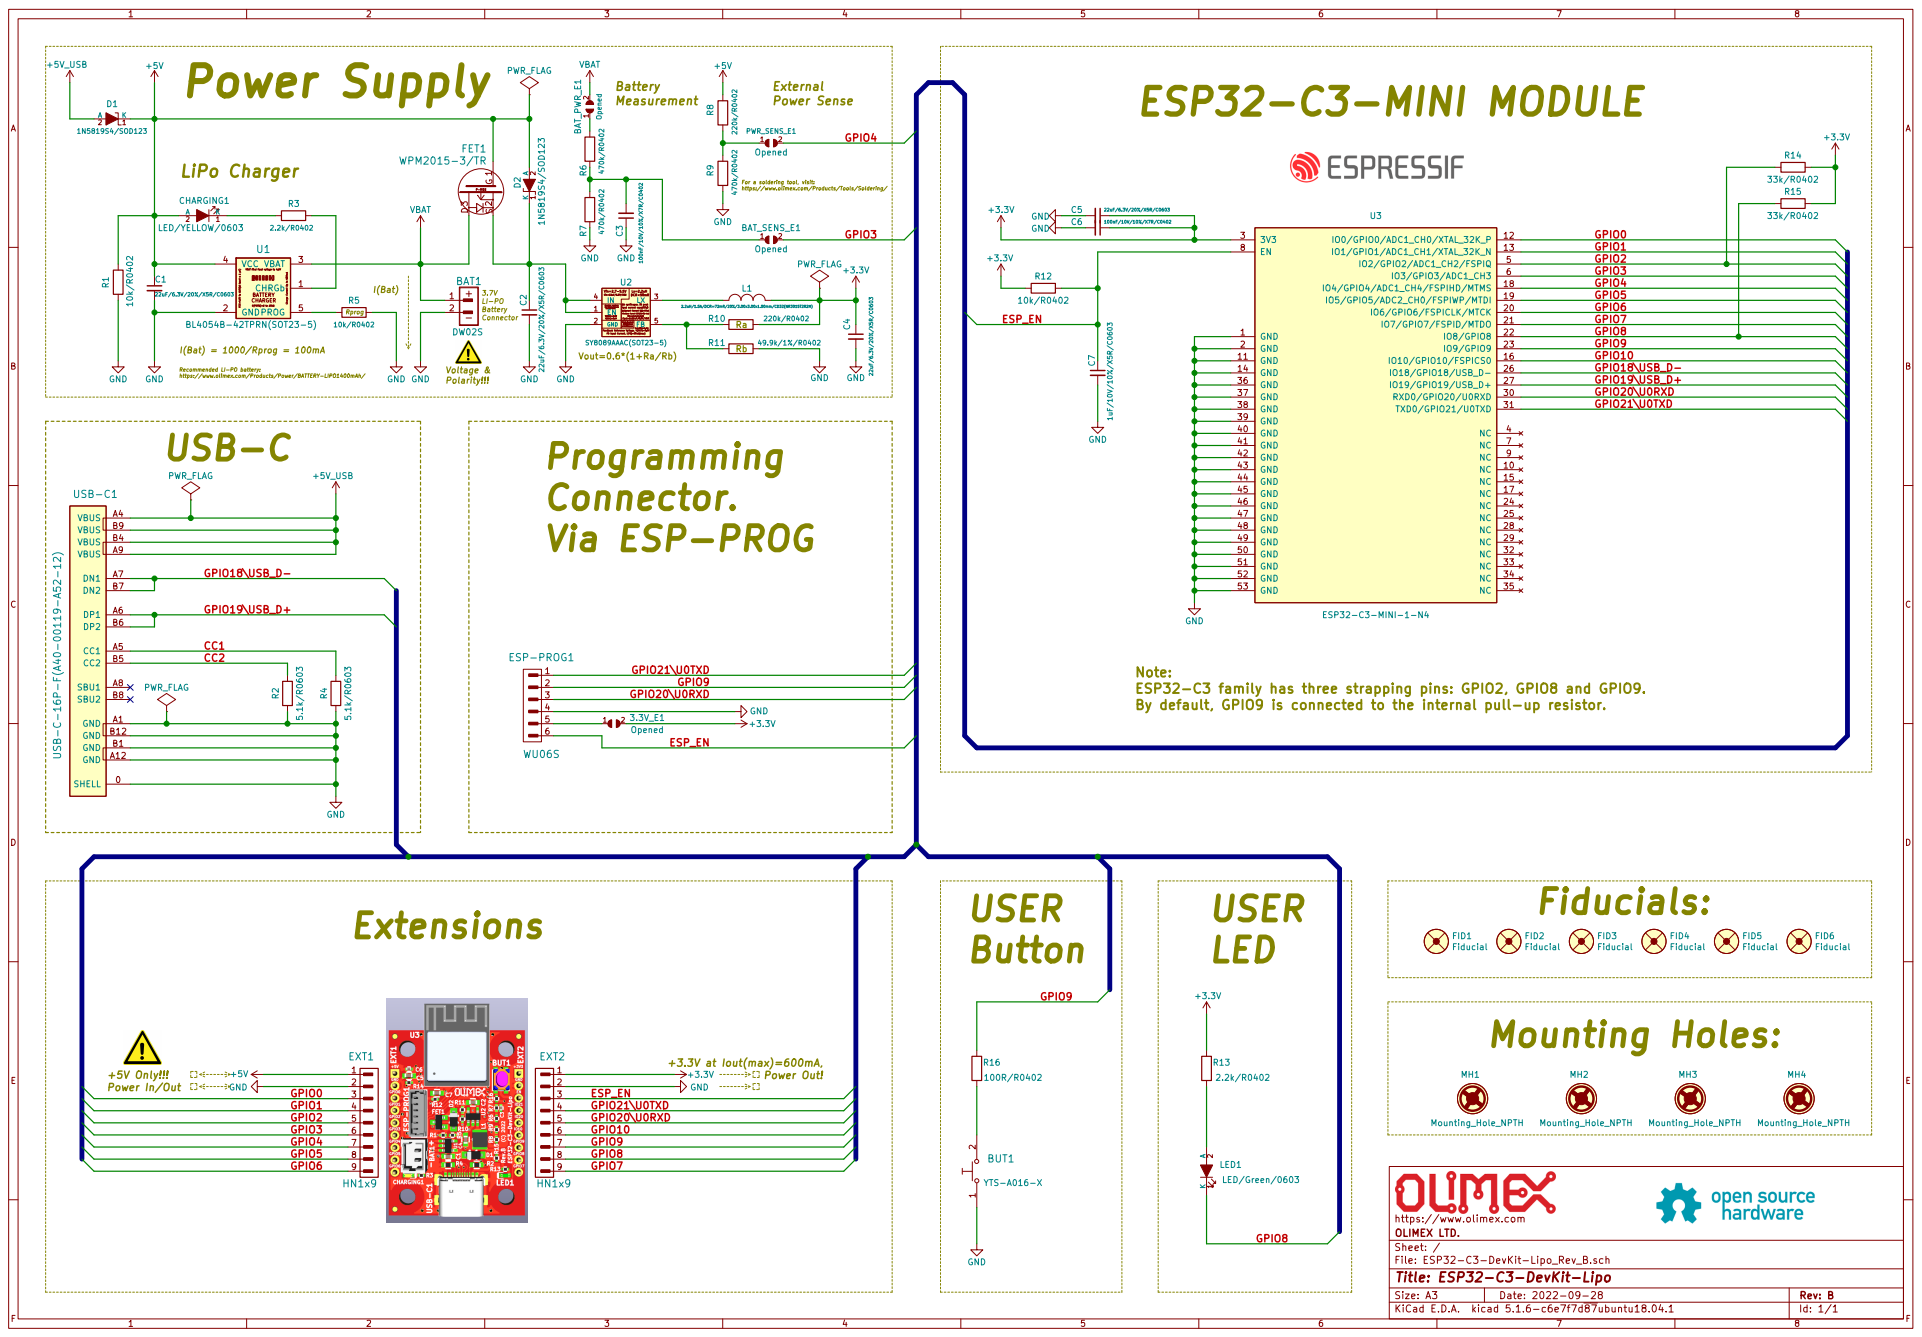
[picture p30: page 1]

ESP32-C3-MINI MODULE Battery Measurement Extensions

For a soldering tool, visit: https://www.olimex.com/Products/Tools/Soldering/

load current capability! Lx=2.2uH

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

Recommended LI-PO battery: https://www.olimex.com/Products/Power/BATTERY-LIPO1400mAh/ USB-C

By default, GPIO9 is connected to the internal pull-up resistor.

+5V Only!!! Power In/Out

File: ESP32-C3-DevKit-Lipo_Rev_B.sch Sheet: / OLIMEX LTD. https://www.olimex.com

Id: 1/1 Title: ESP32-C3-DevKit-Lipo

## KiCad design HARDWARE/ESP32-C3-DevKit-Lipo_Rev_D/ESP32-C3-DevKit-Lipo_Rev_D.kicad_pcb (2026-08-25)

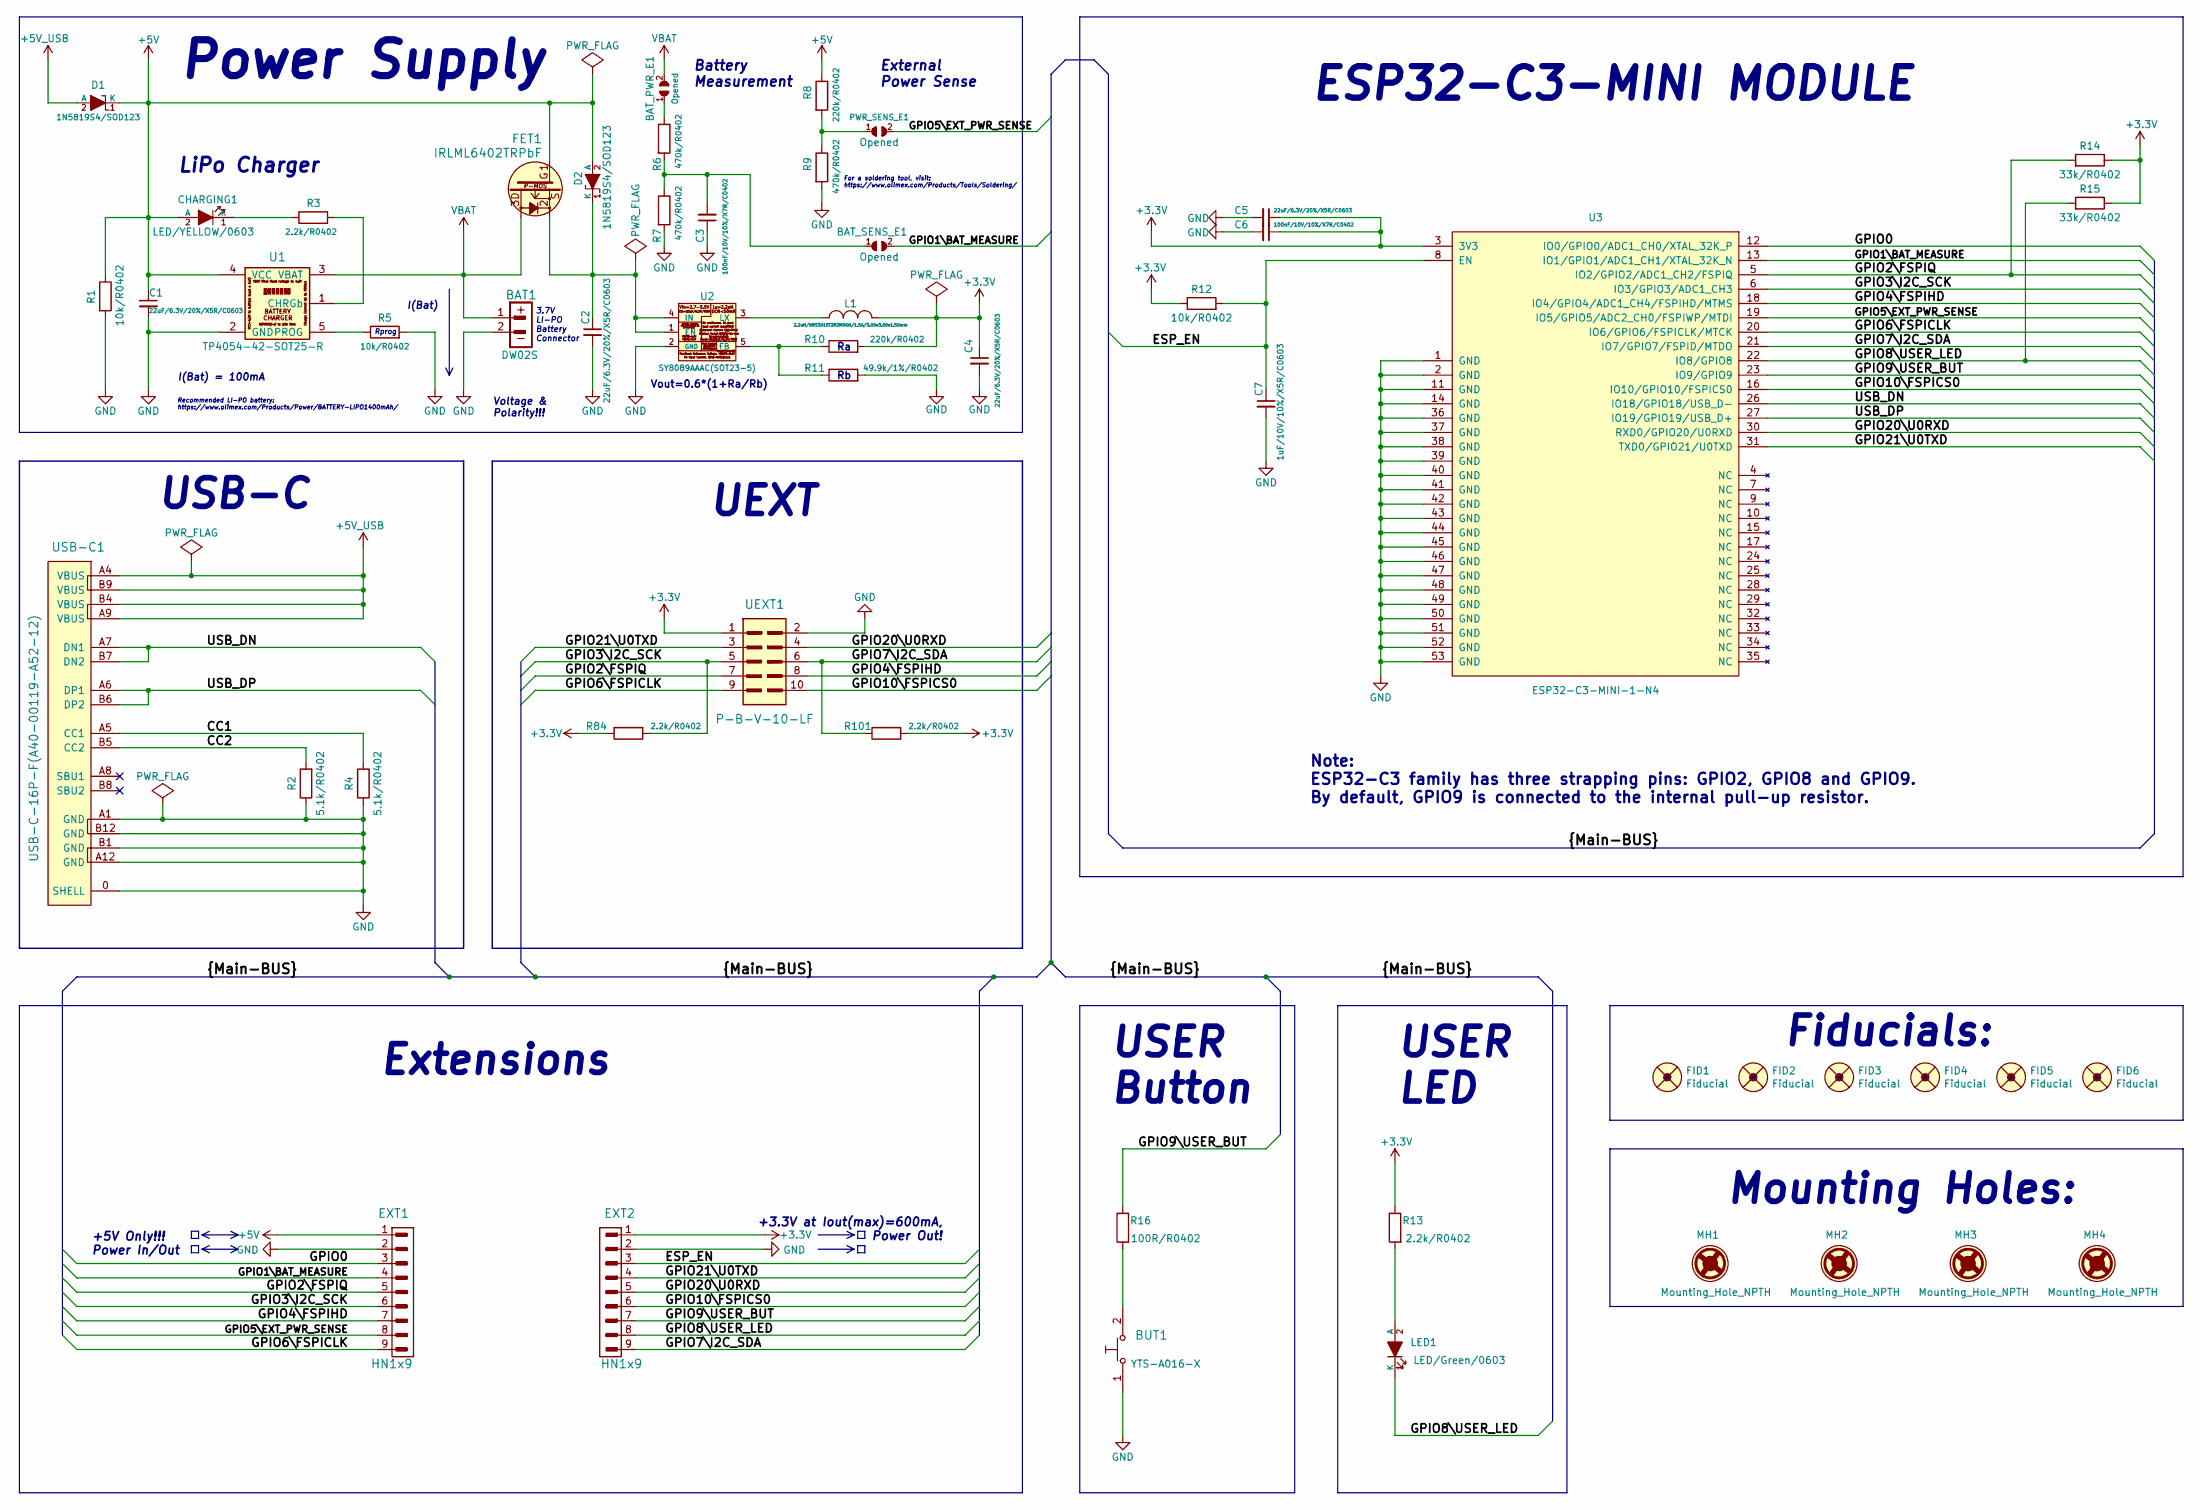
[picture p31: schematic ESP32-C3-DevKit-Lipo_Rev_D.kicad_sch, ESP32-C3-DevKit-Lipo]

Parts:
BAT1: DW02S; LIPO_BAT_VERTICAL_DW02S
BAT_PWR_E1: Opened; SJ_1_SMALLER
BAT_SENS_E1: Opened; SJ_1_SMALLER
BUT1: YTS-A016-X
C1, C2, C4, C5: 22uF/6.3V/20%/X5R/C0603; C_0603_5MIL_DWS
C3, C6: 100nF/10V/10%/X7R/C0402; C_0402_5MIL_DWS
C7: 1uF/10V/10%/X5R/C0603; C_0603_5MIL_DWS
CHARGING1: LED/YELLOW/0603; LED_0603_KA
D1, D2: 1N5819S4/SOD123; SOD-123_1C-2A_KA
EXT1, EXT2: HN1x9
FET1: IRLML6402TRPbF; SOT23
FID1, FID3, FID4, FID6: Fiducial; Fiducial1x3
FID2, FID5: Fiducial; Fiducial1x3_Paste
L1: 2.2uH/NRS3015T2R2MNGH/1.5A/3.00x3.00x1.50mm; CD32
LED1: LED/Green/0603; LED_0603_KA
MH1, MH2, MH3, MH4: Mounting_Hole_NPTH; Mounting_Hole_Drill-3.3mm_Clerance-7mm
PWR_SENS_E1: Opened; SJ_1_SMALLER
R1, R5, R12: 10k/R0402; R_0402_5MIL_DWS
R2, R4: 5.1k/R0402; R_0402_5MIL_DWS
R3, R13, R84, R101: 2.2k/R0402; R_0402_5MIL_DWS
R6, R7, R9: 470k/R0402; R_0402_5MIL_DWS
R8, R10: 220k/R0402; R_0402_5MIL_DWS
R11: 49.9k/1%/R0402; R_0402_5MIL_DWS
R14, R15: 33k/R0402; R_0402_5MIL_DWS
R16: 100R/R0402; R_0402_5MIL_DWS
U1: TP4054-42-SOT25-R; SOT-23-5
U2: SY8089AAAC(SOT23-5); SOT-23-5
U3: ESP32-C3-MINI-1-N4; ESP32-­C3-­MINI­-1
UEXT1: P-B-V-10-LF; GBH-254-SMT-10
USB-C1: USB-C-16P-F(A40-00119-A52-12); USB2.0_TYPE-C(A40-00119-A52-12)

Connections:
+3.3V: C4.1, C5.1, C6.1, EXT2.1, L1.2, R10.2, R12.1, R13.1, R14.1, R15.1, U3.3 (3V3), UEXT1.1; also elsewhere on the board
+5V: C1.1, CHARGING1.2 (A), D1.1 (K), D2.2 (A), EXT1.1, FET1.1, R1.1, R8.1, U1.4 (VCC)
+5V_USB: D1.2 (A), USB-C1.A4 (VBUS), USB-C1.A9 (VBUS), USB-C1.B4 (VBUS), USB-C1.B9 (VBUS)
/CC1: R4.2, USB-C1.A5 (CC1)
/CC2: R2.2, USB-C1.B5 (CC2)
/ESP_EN: C7.1, EXT2.3, R12.2, U3.8 (EN)
/GPIO0: EXT1.3, U3.12 (IO0/GPIO0/ADC1_CH0/XTAL_32K_P)
/GPIO1\BAT_MEASURE: BAT_SENS_E1.2, EXT1.4, U3.13 (IO1/GPIO1/ADC1_CH1/XTAL_32K_N)
/GPIO2\FSPIQ: EXT1.5, R14.2, U3.5 (IO2/GPIO2/ADC1_CH2/FSPIQ), UEXT1.7
/GPIO3\I2C_SCK: EXT1.6, U3.6 (IO3/GPIO3/ADC1_CH3), UEXT1.5; also elsewhere on the board
/GPIO4\FSPIHD: EXT1.7, U3.18 (IO4/GPIO4/ADC1_CH4/FSPIHD/MTMS), UEXT1.8
/GPIO5\EXT_PWR_SENSE: EXT1.8, PWR_SENS_E1.2, U3.19 (IO5/GPIO5/ADC2_CH0/FSPIWP/MTDI)
/GPIO6\FSPICLK: EXT1.9, U3.20 (IO6/GPIO6/FSPICLK/MTCK), UEXT1.9
/GPIO7\I2C_SDA: EXT2.9, U3.21 (IO7/GPIO7/FSPID/MTDO), UEXT1.6; also elsewhere on the board
/GPIO8\USER_LED: EXT2.8, LED1.1 (K), R15.2, U3.22 (IO8/GPIO8)
/GPIO9\USER_BUT: EXT2.7, R16.1, U3.23 (IO9/GPIO9)
/GPIO10\FSPICS0: EXT2.6, U3.16 (IO10/GPIO10/FSPICS0), UEXT1.10
/GPIO20\U0RXD: EXT2.5, U3.30 (RXD0/GPIO20/U0RXD), UEXT1.4
/GPIO21\U0TXD: EXT2.4, U3.31 (TXD0/GPIO21/U0TXD), UEXT1.3
/USB_DN: U3.26 (IO18/GPIO18/USB_D-), USB-C1.A7 (DN1), USB-C1.B7 (DN2)
/USB_DP: U3.27 (IO19/GPIO19/USB_D+), USB-C1.A6 (DP1), USB-C1.B6 (DP2)
GND: BAT1.2, BUT1.1, C1.2, C2.2, C3.1, C4.2, C5.2, C6.2, C7.2, EXT1.2, EXT2.2, R1.2, R2.1, R4.1, R5.2, R7.2, R9.2, R11.2, U1.2 (GND), U2.2 (GND), U3.1 (GND), U3.2 (GND), U3.11 (GND), U3.14 (GND), U3.36 (GND), U3.37 (GND), U3.38 (GND), U3.39 (GND), U3.40 (GND), U3.41 (GND), U3.42 (GND), U3.43 (GND), U3.44 (GND), U3.45 (GND), U3.46 (GND), U3.47 (GND), U3.48 (GND), U3.49 (GND), U3.50 (GND), U3.51 (GND), U3.52 (GND), U3.53 (GND), UEXT1.2, USB-C1.0 (SHELL), USB-C1.A1 (GND), USB-C1.A12 (GND), USB-C1.B1 (GND), USB-C1.B12 (GND)
unnamed: BAT_PWR_E1.1, R6.1
unnamed: BAT_SENS_E1.1, C3.2, R6.2, R7.1
unnamed: BUT1.2, R16.2
unnamed: CHARGING1.1 (K), R3.1
unnamed: C2.1, D2.1 (K), FET1.2, U2.1 (EN), U2.4 (IN)
unnamed: LED1.2 (A), R13.2
unnamed: PWR_SENS_E1.1, R8.2, R9.1
unnamed: R3.2, U1.1 (CHRGb)
unnamed: R5.1, U1.5 (PROG)
unnamed: R10.1, R11.1, U2.5 (FB)
unnamed: L1.1, U2.3 (LX)
VBAT: BAT1.1, BAT_PWR_E1.2, FET1.3, U1.3 (VBAT)

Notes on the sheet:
USER Button
Mounting Holes:
Note: ESP32-C3 family has three strapping pins: GPIO2, GPIO8 and GPIO9. By default, GPIO9 is connected to the internal pull-up resistor.
Recommended LI-PO battery: https://www.olimex.com/Products/Power/BATTERY-LIPO1400mAh/
ESP32-C3-MINI MODULE
Voltage & Polarity!!!
3.7V LI-PO Battery Connector
Vout=0.6*(1+Ra/Rb)
+3.3V at Iout(max)=600mA, Power Out!
LiPo Charger
USER LED
Extensions
Battery Measurement
+5V Only!!! Power In/Out
For a soldering tool, visit: https://www.olimex.com/Products/Tools/Soldering/
UEXT
External Power Sense
I(Bat) = 100mA
USB-C
Power Supply
Fiducials:
I(Bat)
Rprog

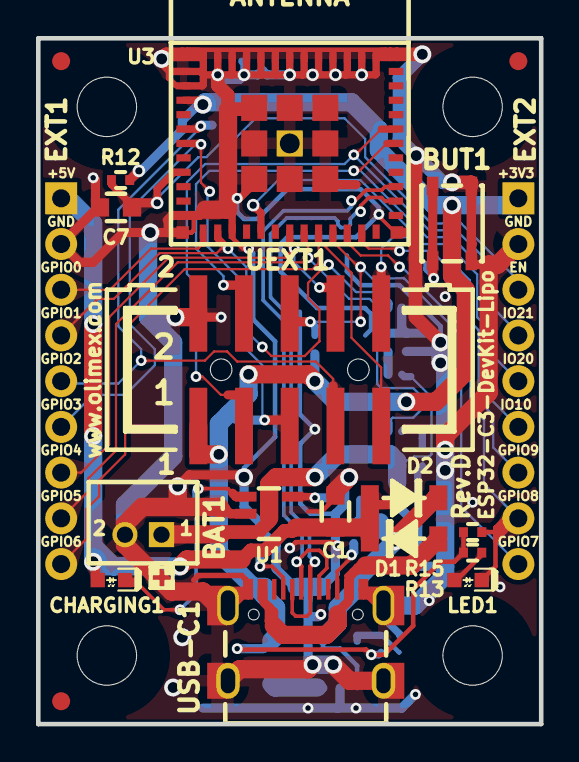
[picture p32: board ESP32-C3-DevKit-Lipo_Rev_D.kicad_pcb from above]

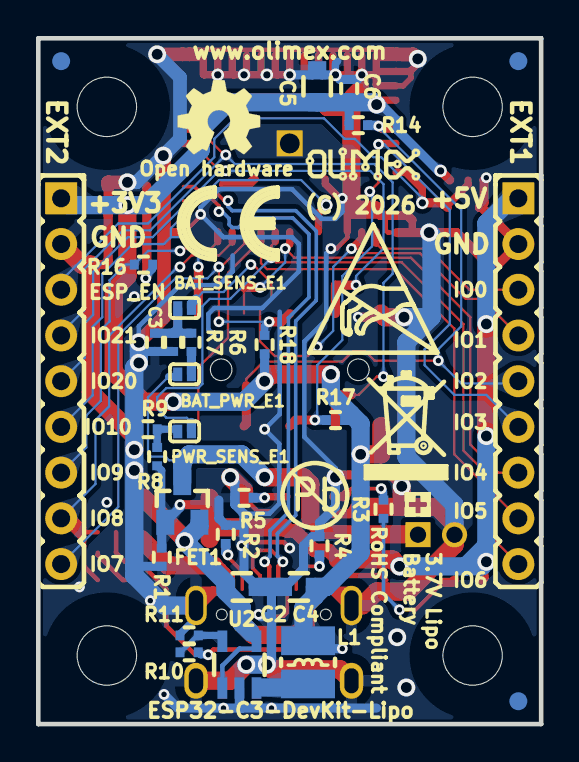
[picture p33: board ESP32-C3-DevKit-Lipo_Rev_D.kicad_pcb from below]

Board: 2 copper layers, 27.9 x 38.1 mm, 59 parts (37 on the bottom side), 34 nets.

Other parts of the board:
Logo_OLIMEX_2: Logo_OLIMEX_2; Logo_OLIMEX_80
R17, R18: 2.2k/R0402; R_0402_5MIL_DWS
Sign_Antistatic: Sign_Antistatic
Sign_CE: CE_Sign
Sign_OSHW_7.3x6.0mm: Sign_OSHW_7.3x6.0mm; Sign_OSHW_7.3x6.0mmn
Sign_PB-Free: Sign_PB-Free
Sign_RecycleBin_1: Sign_RecycleBin_1

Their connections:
+3.3V: R17.1, R18.2; also elsewhere on the board
/GPIO3\I2C_SCK: R17.2; also elsewhere on the board
/GPIO7\I2C_SDA: R18.1; also elsewhere on the board

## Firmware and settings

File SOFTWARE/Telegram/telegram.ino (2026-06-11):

/*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
Olimex ESP32-C3-DevKit-Lipo https://www.olimex.com/Products/IoT/ESP32-C3/ESP32-C3-DevKit-Lipo/open-source-hardware
  push button - GPIO9	or Door magnetic switch https://www.olimex.com/Products/Components/Switches/MAG-SW/
  LED status  - GPIO8
  PIR sensor  - GPIO0	https://www.olimex.com/Products/Breadboarding/Sensors/PIR-SB312/

  The project is described here: https://olimex.wordpress.com/2026/06/11/home-automation-with-phone-notifications-for-under-e5-yes-its-possible/
  
*/

#include <WiFi.h>
#include <WiFiClientSecure.h>
#include <UniversalTelegramBot.h>
#include <ArduinoJson.h>

// Set GPIOs for LED, reedswitch and PIR sensor
const int reedSwitch = 9;
const int led = 8; //optional
const int pirSensor = 0;

// Detects whenever the door changed state
bool changeState = false;

// Detects whenever the PIR sensor triggered
bool pirTriggered = false;

// Holds reedswitch state (1=opened, 0=close)
bool state;
String doorState;

// Auxiliary variables (it will only detect changes that are 1500 milliseconds apart)
unsigned long previousMillis = 0;
const long interval = 1500;

// PIR debounce: ignore re-triggers within 5000 ms
unsigned long pirPreviousMillis = 0;
const long pirInterval = 5000;

const char* ssid = "REPLACE_WITH_YOUR_SSID";
const char* password = "REPLACE_WITH_YOUR_PASSWORD";

// Initialize Telegram BOT
#define BOTtoken "XXXXXXXXXX:XXXXXXXXXXXXXXXXXXXXXXXXXXXXXXXXXXX"  // your Bot Token (Get from Botfather)

// Use @myidbot to find out the chat ID of an individual or a group
// Also note that you need to click "start" on a bot before it can
// message you
#define CHAT_ID "XXXXXXXXXX"

WiFiClientSecure client;
UniversalTelegramBot bot(BOTtoken, client);

// Runs whenever the reedswitch changes state
ICACHE_RAM_ATTR void changeDoorStatus() {
  Serial.println("Door State changed");
  changeState = true;
}

// Runs whenever the PIR sensor detects motion (output goes HIGH)
ICACHE_RAM_ATTR void motionDetected() {
  pirTriggered = true;
}

void setup() {
  // Serial port for debugging purposes
  Serial.begin(115200);  

  // Read the current door state
  pinMode(reedSwitch, INPUT_PULLUP);
  state = digitalRead(reedSwitch);

  // Set LED state to match door state
  pinMode(led, OUTPUT);
  digitalWrite(led, !state);
  
  // Set the reedswitch pin as interrupt, assign interrupt function and set CHANGE mode
  attachInterrupt(digitalPinToInterrupt(reedSwitch), changeDoorStatus, CHANGE);

  // Set PIR sensor pin as input and attach interrupt on RISING edge (output goes HIGH)
  pinMode(pirSensor, INPUT);
  attachInterrupt(digitalPinToInterrupt(pirSensor), motionDetected, RISING);

  // Connect to Wi-Fi
  WiFi.mode(WIFI_STA);
  WiFi.begin(ssid, password);
  client.setCACert(TELEGRAM_CERTIFICATE_ROOT); // Add root certificate for api.telegram.org
  while (WiFi.status() != WL_CONNECTED) {
    delay(500);
    Serial.print(".");
  }
  Serial.println("");
  Serial.println("WiFi connected");  

  bot.sendMessage(CHAT_ID, "ESP32-C3 Bot started up", "");
}

void loop() {
  if (changeState){
    unsigned long currentMillis = millis();
    if(currentMillis - previousMillis >= interval) {
      previousMillis = currentMillis;
      // If a state has occurred, invert the current door state   
        state = !state;
        if(state) {
          doorState = "closed";
        }
        else{
          doorState = "open";
        }
        digitalWrite(led, !state);
        changeState = false;
        Serial.println(state);
        Serial.println(doorState);
        
        //Send notification
        bot.sendMessage(CHAT_ID, "The door is " + doorState, "");
    }
  }

  if (pirTriggered) {
    unsigned long currentMillis = millis();
    if (currentMillis - pirPreviousMillis >= pirInterval) {
      pirPreviousMillis = currentMillis;
      pirTriggered = false;
      Serial.println("Motion detected");
      bot.sendMessage(CHAT_ID, "Motion detected", "");
    } else {
      pirTriggered = false;
    }
  }
}

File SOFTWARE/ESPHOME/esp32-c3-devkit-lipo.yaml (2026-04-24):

esphome:
  name: esp32-c3-devkit-lipo
  comment: Olimex ESP32-C3-DevKit-LiPo (native USB, LiPo, UEXT)

esp32:
  board: esp32-c3-devkitm-1
  framework:
    type: arduino

# ================= CORE =================

logger:
  hardware_uart: USB_CDC

api:

ota:
  - platform: esphome

# ================= WIFI =================

wifi:
  ssid: !secret wifi_ssid
  password: !secret wifi_password

  ap:
    ssid: "ESP32-C3-LiPo Fallback"
    password: "fallback123"

captive_portal:

# ================= ONBOARD LED =================

output:
  - platform: gpio
    id: led_green_out
    pin:
      number: GPIO8
      mode: OUTPUT
      inverted: false

light:
  - platform: binary
    name: "Onboard LED"
    output: led_green_out

# ================= USER BUTTON =================

binary_sensor:
  - platform: gpio
    name: "User Button"
    pin:
      number: GPIO9
      mode: INPUT_PULLUP
      inverted: true
    filters:
      - delayed_on: 10ms
      - delayed_off: 10ms

# GPIO9 is a boot strapping pin.
# Holding the button during reset may prevent boot.

# ================= OPTIONAL (REQUIRES JUMPERS) =================

# ---- External Power Sense (GPIO5) ----
# Requires hardware jumper to be CLOSED
#
#binary_sensor:
#  - platform: gpio
#    name: "External Power Present"
#    pin:
#      number: GPIO5
#      mode: INPUT

# ---- Battery Voltage (GPIO1 via divider) ----
# Requires hardware jumper to be CLOSED
# Divider: 470k / 470k → multiply by 2
#
#sensor:
#  - platform: adc
#    pin: GPIO1
#    name: "Battery Voltage"
#    attenuation: 12db
#    update_interval: 10s
#    filters:
#      - multiply: 2.0

# ================= UEXT =================

uart:
  - id: uext_uart
    tx_pin: GPIO21
    rx_pin: GPIO20
    baud_rate: 115200

i2c:
  - id: uext_i2c
    scl: GPIO3
    sda: GPIO7
    scan: true

spi:
  - id: uext_spi
    clk_pin: GPIO6
    mosi_pin: GPIO10
    miso_pin: GPIO2

# ================= NOTES =================
#
# GPIO1 (ADC) and GPIO5 are NOT available unless
# corresponding board jumpers are populated.
#
# This config keeps default firmware safe for
# out-of-the-box hardware state.
#
# Enable those sections only after closing jumpers.
#
# Avoid using GPIO4 (FSPIHD) unless you know exactly
# what you're doing with SPI flash modes.

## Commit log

2022-10-06 inisital commit
    [ESP32-C3-DevKit-Lipo_Rev_B-BOM.ods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]
2022-10-07 add user manual
    [ESP32-C3-DevKit-Lipo_Rev_A-BOM.ods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]
2024-04-05 Create ESP32-C3-DevKit-Lipo-dimensions.pdf
    Added dimensions
2026-03-20 Update
    New hardware revision C
    [ESP32-C3-DevKit-Lipo_Rev_C-B_Cu.gbr, ESP32-C3-DevKit-Lipo_Rev_C-B_Mask.gbr, ESP32-C3-DevKit-Lipo_Rev_C-B_Paste.gbr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]
2026-08-25 Update
    Added hardware revision D changes
    [ESP32-C3-DevKit-Lipo_Rev_D-B_Cu.gbr, ESP32-C3-DevKit-Lipo_Rev_D-B_Mask.gbr, ESP32-C3-DevKit-Lipo_Rev_D-B_Paste.gbr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]

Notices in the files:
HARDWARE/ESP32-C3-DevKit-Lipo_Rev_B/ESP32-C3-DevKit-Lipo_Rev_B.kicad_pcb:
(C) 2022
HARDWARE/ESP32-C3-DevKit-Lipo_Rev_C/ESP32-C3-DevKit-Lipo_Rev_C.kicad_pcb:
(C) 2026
